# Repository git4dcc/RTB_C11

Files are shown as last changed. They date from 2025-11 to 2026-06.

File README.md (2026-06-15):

# RTB_C11





Smart Power Protection: This homebrew powerboard actively monitors input voltage to safeguard connected RTB modules. It automatically interrupts power to the RTB subsystem if the voltage drifts outside the **safe range of 12V to 18V**, preventing damage from erroneous power conditions.

<details>
<summary>See also</summary>

- [RTB_C10 - Master](/../../../../git4dcc/RTB_C10)
- [RTB_C12 - Micro Booster](/../../../../git4dcc/RTB_C12)
- [RTB_C13 - Track Sensor](/../../../../git4dcc/RTB_C13)
- [RTB_P15 - Base](/../../../../git4dcc/RTB_P15)

</details>

<details>
<summary>User Guides</summary>

- User Guide - DE
- [User Guide - EN](https://rtb4dcc.de/rtb_user_guide_en/)

</details>

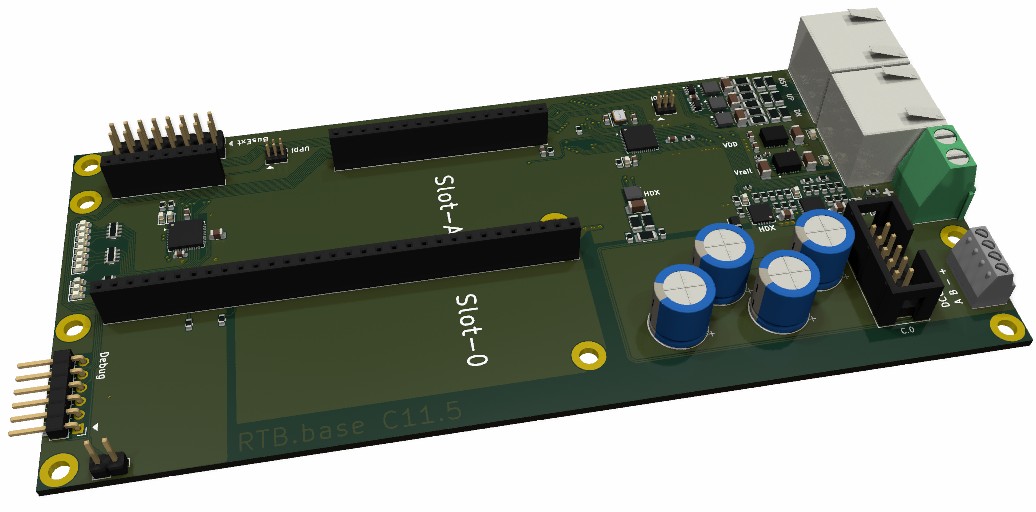
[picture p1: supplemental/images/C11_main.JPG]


## Powerboard features
- **FDX bus**
  - 2Mbps full duplex, RS-485 differential
- **HDX bus**
  - 2Mb, half duplex, RS-485 differential
  - up to 2A DCC continuous current
  - up to 2A HDX continuous current
- **Power input**
  - Under-, Over-, Reverse voltage protection
  - 14-18V DC, >4A
  - Soft start
  - Short circuit detection with software configurable latch-off, hiccup or current limiter mode
- **Expansion slots**
  - Bus Master Slot (Slot-A)
  - Booster Slot (Slot-0)
- firmware update over the bus

# Hardware
The PCB layout uses SMD footprints with 0.4mm pitch and a mix of 0603 and 0402 parts. Reflow soldering is mandatory.

| top | bottom |
| --- | --- |
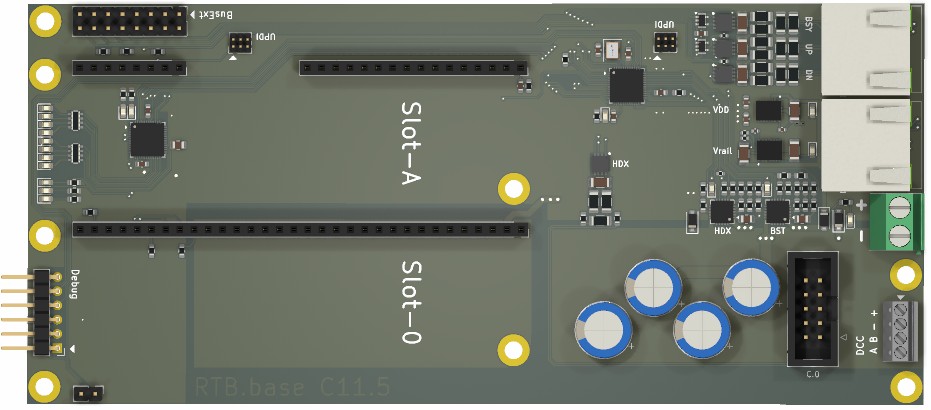
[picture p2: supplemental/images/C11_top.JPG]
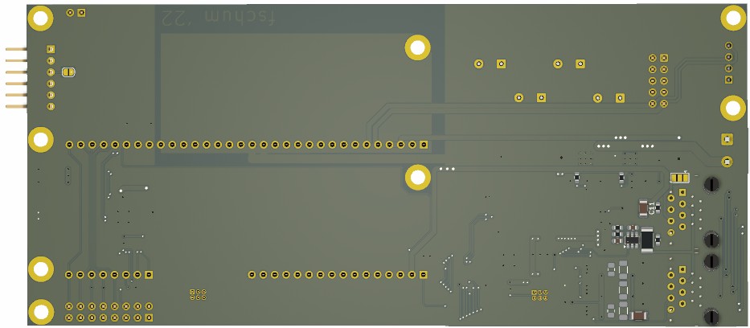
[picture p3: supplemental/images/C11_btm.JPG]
|  |  |

## PCB
- 2-layer PCB, FR4, 1.6mm
- CPU: AVR64DA48, Atmega4809
- PMIC: MAX17613AATP+

## Kicad
[Schematic](doc/C11_schematic.pdf) | [Layout](doc/C11_layout.pdf) | [Gerber](gerber)

# Firmware
Filename structure: { **pcb** }{ **code** }{ **version** }.hex

Example: **C11F0001**.hex

| | Description |
| --- | --- |
| **pcb** | Name of matching hardware (**C11**) |
| **code** | Type of code contained (**R**=rom, **B**=bootloader, **F**=flash, **U**=bld update, **P**=UPDI factory code) |
| **version** | Release version (**####**) |

[Firmware files](firmware)

## UPDI / Fuses
The fuse settings as well as the P-code (C11Pxxxx.hex) has to be installed by using UPDI.<br>

| Fuses Setting |
| --- |
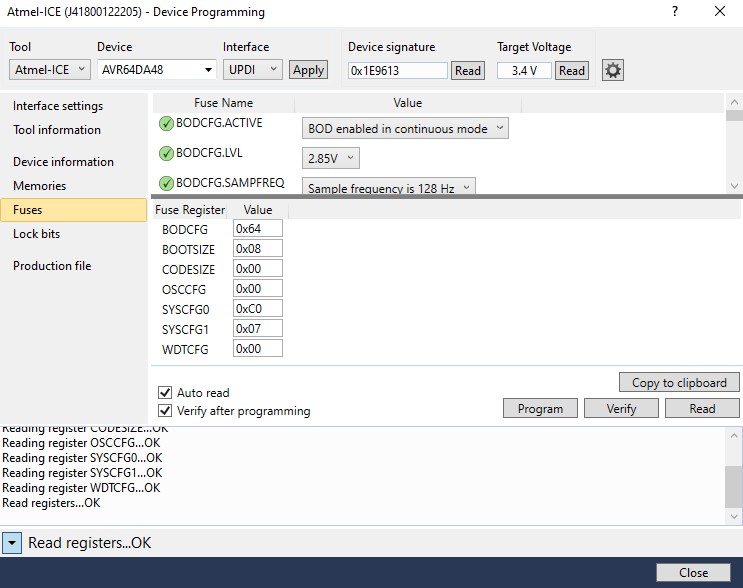
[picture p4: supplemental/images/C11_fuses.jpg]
||

# Images
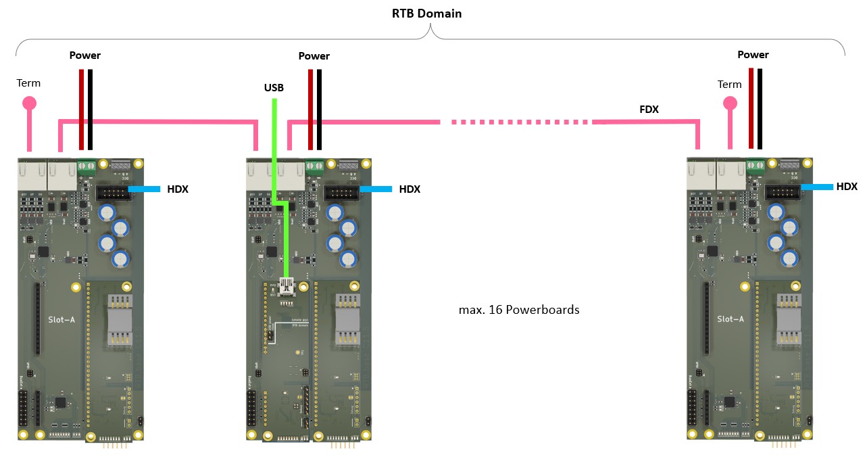
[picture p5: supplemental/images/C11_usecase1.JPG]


| Standalone | Closeup | FDX + HDX bus connected |
| --- | --- | --- |
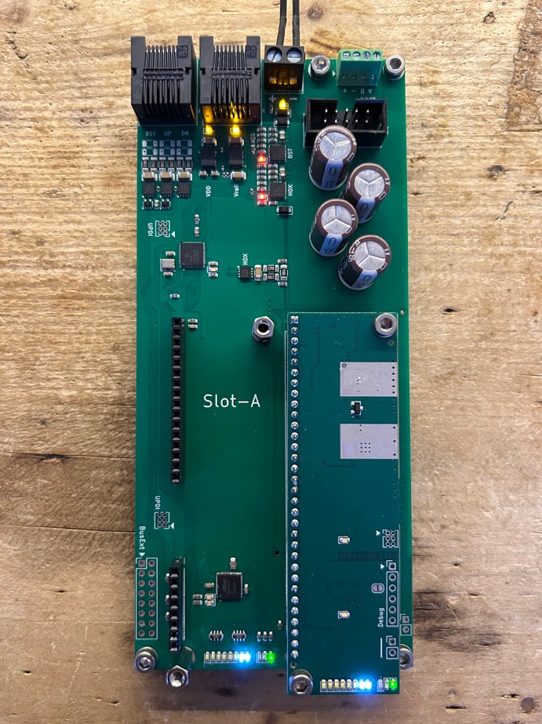
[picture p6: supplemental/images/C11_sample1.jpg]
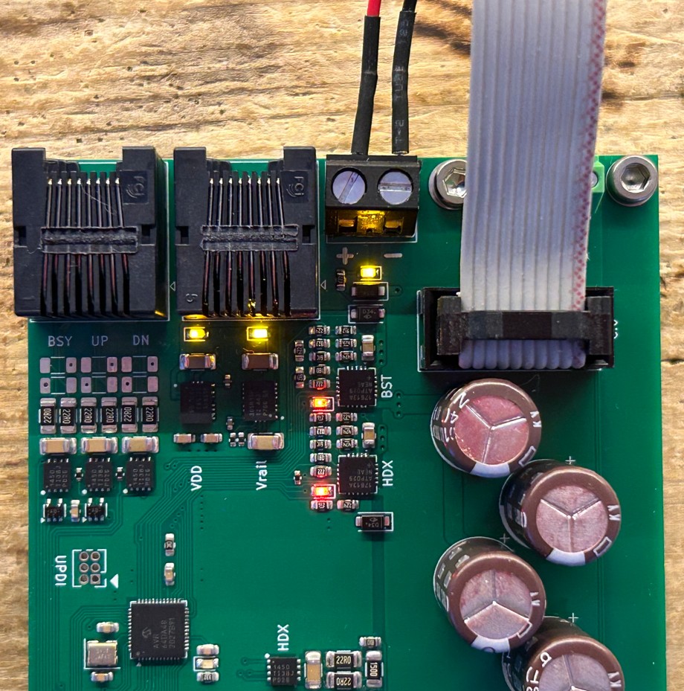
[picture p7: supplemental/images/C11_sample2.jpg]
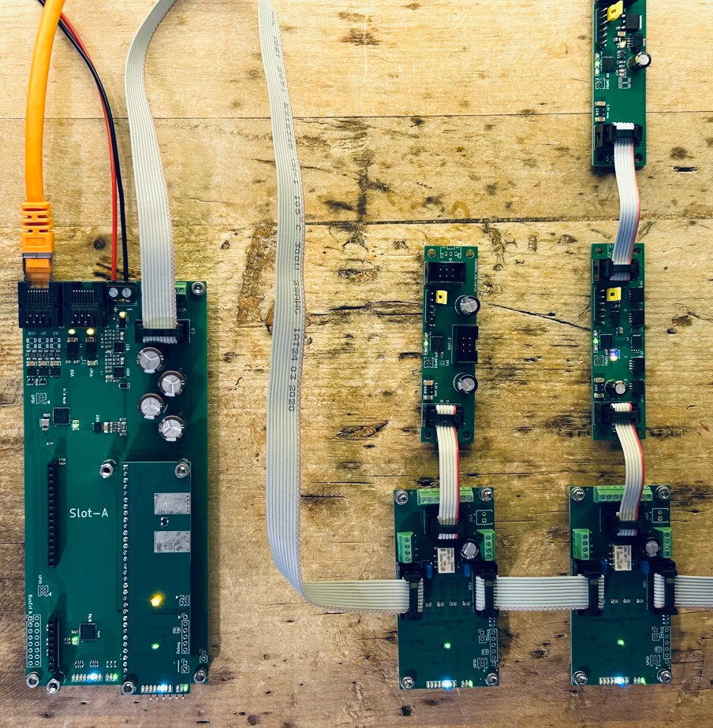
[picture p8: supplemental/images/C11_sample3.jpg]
|  |  |  |

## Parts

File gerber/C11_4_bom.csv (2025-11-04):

Designator | Footprint | Quantity | Value | LCSC Part #
C10, C2, C27, C7, C8, C9 | 1206 | 6 | 2.2u/50V | C50254
C11, C26 | 1206 | 2 | 10u | C694197
C12, C31 | 0603 | 2 | 10u/25V | C96446
C13, C21, C22, C24, C25, C28, C3, C5, C6 | 0603 | 9 | 100n | C14663
C14, C16 | 0805 | 2 | 1u/50V | C28323
C19 | 1206 | 1 | 2.2u | C50254
C20 | 0805 | 1 | 100n | C49678
C23 | 0603 | 1 | 2.2u | C50254
C32, C4 | 0402 | 2 | 1u | C52923
D1, D5, D9 | D_SOD-123F | 3 | SSA34 | C84632
IC1, IC7 | TPSM365R3RDNR | 2 | TPSM365R15RDNR | C22427405
IC2, IC3, IC4, IC5 | SON65P300X300X100-9N-D | 4 | THVD1450DRBR | C1850226
IC6, IC8 | UQFN-20-1EP_4x4mm_P0.5mm_EP2.8x2.8mm_ThermalVias | 2 | MAX17613AATP+ | C3198161
R1 | 0402 | 1 | 100k | C25741
R11 | 1206 | 1 | 150 | C17917
R12, R14, R18, R19 | 0603 | 4 | 220k | C22961
R13, R20, R27, R28 | 0603 | 4 | 9.1k | C23260
R2 | 0402 | 1 | 9.1k | C25926
R21, R23, R36, R38, R43, R45 | 0603 | 6 | 470k | C23178
R22, R37 | 0603 | 2 | 42.2k | C23167
R24, R39 | 0603 | 2 | 82k | C23254
R25, R40 | 0603 | 2 | 150k | C22807
R26, R41 | 0603 | 2 | 2.2k | C4190
R29, R46, R47, R49, R50, R72, R80, R81, R91 | 0603 | 9 | 3.3k | C22978
R4, R82, R88, R9, R90 | 0603 | 5 | 10k | C25804
R42 | 2010 | 1 | 0.05 | C912938
R51, R52, R53 | 0603 | 3 | 4.7k | C23162
R56, R57, R60, R61, R62, R63 | 1206 | 6 | 390 | C25378
R58, R59, R64, R65, R66, R67, R76, R77 | 1206 | 8 | 22 | C17958
R7, R8 | 0603 | 2 | 1k | C21190
R71 | 0603 | 1 | 33k | C4216
R83, R89 | 0603 | 2 | 22k | C31850
R84, R85 | 0402 | 2 | 100 | C25076
R87 | 0402 | 1 | 10k | C25744
RN1, RN2 | R_Array_Concave_4x0603 | 2 | 4.7k | C1980
U1 | QFN-48-1EP_6x6mm_P0.4mm_EP4.2x4.2mm | 1 | AVR64DA48 | C3227406
U3, U4 | SOT-353_SC-70-5 | 2 | 74AHC1G02 | C554271
U7 | SOT-23-6 | 1 | INA181A1 | C2058943
U9 | QFN-48-1EP_6x6mm_P0.4mm_EP4.2x4.2mm | 1 | ATmega4809-A
X1 | Oscillator_SMD_Abracon_ASE-4Pin_3.2x2.5mm | 1 | ASE-24MHz

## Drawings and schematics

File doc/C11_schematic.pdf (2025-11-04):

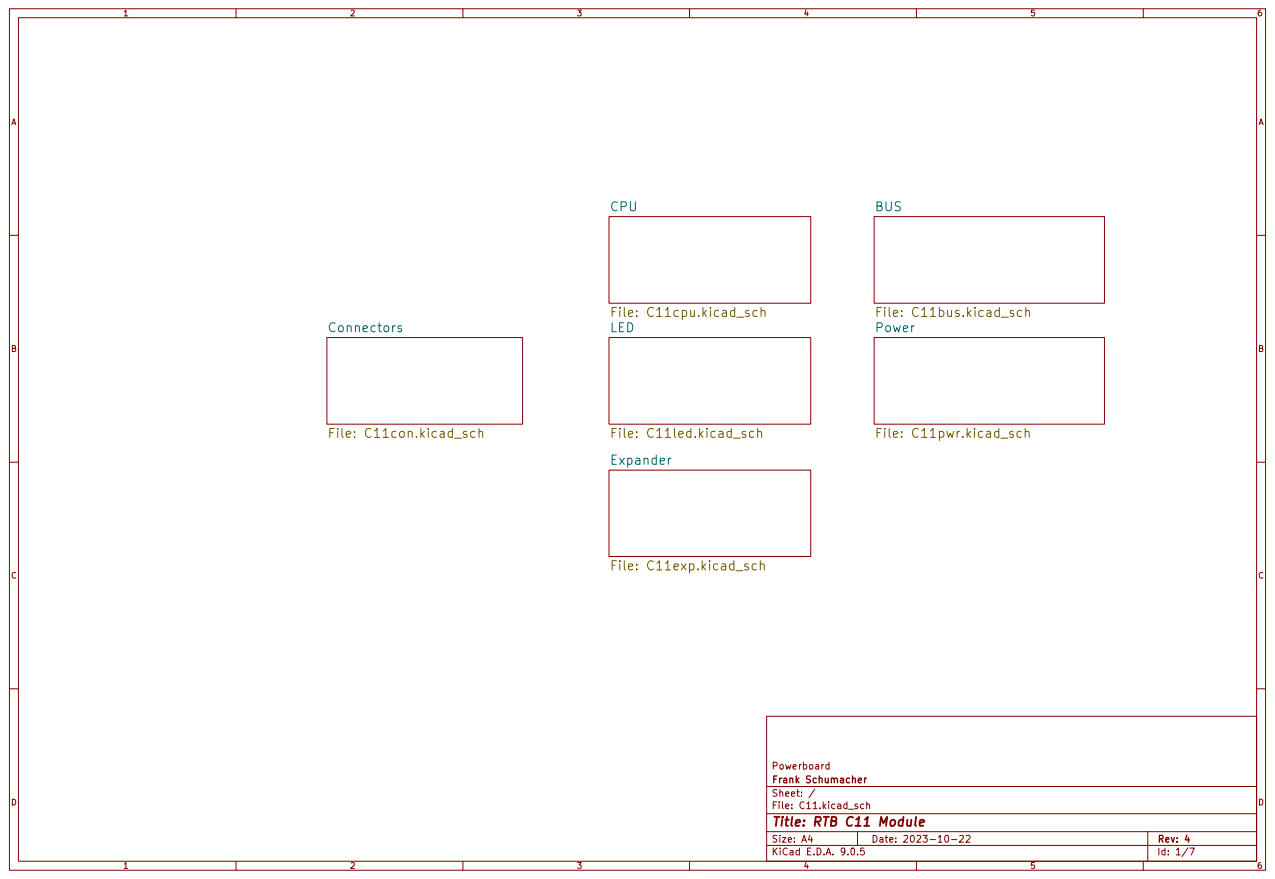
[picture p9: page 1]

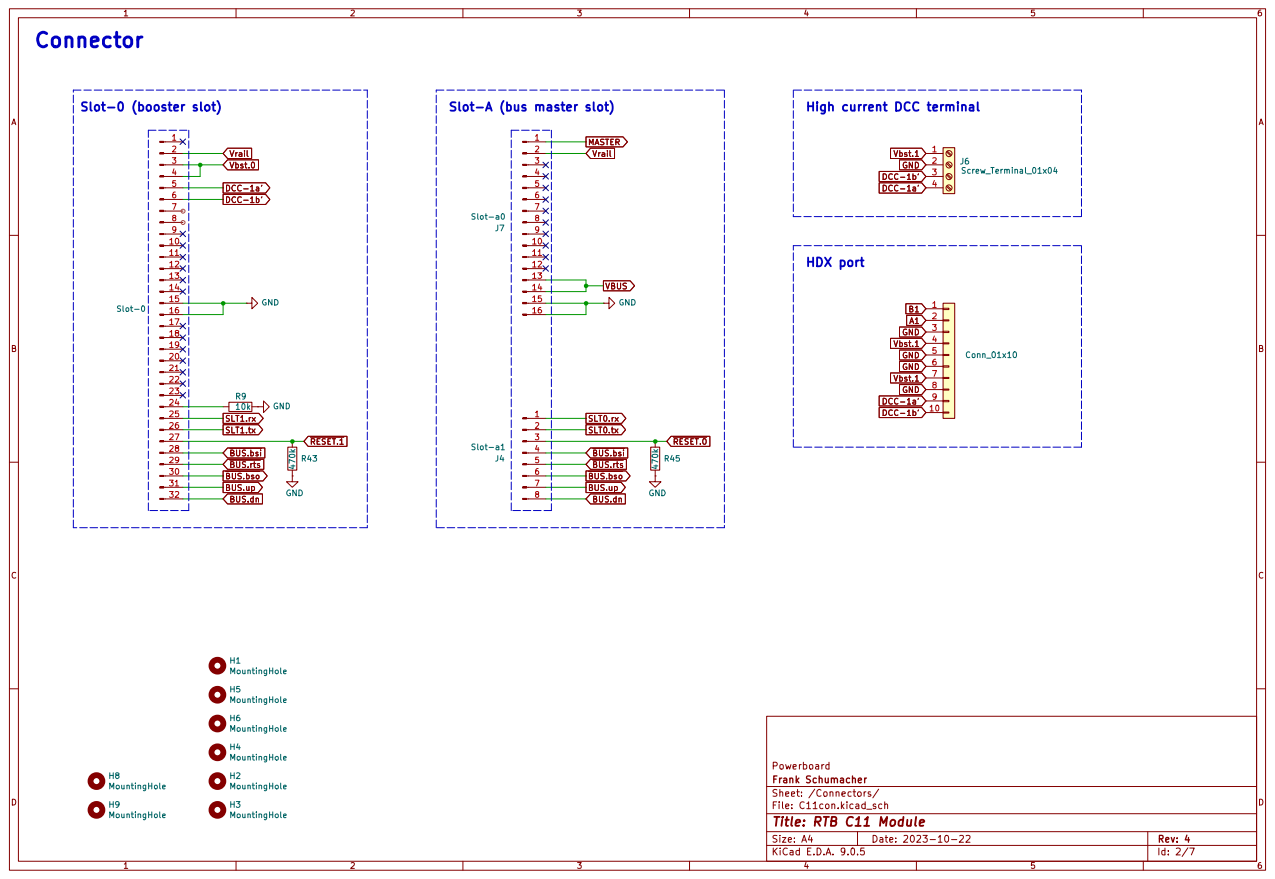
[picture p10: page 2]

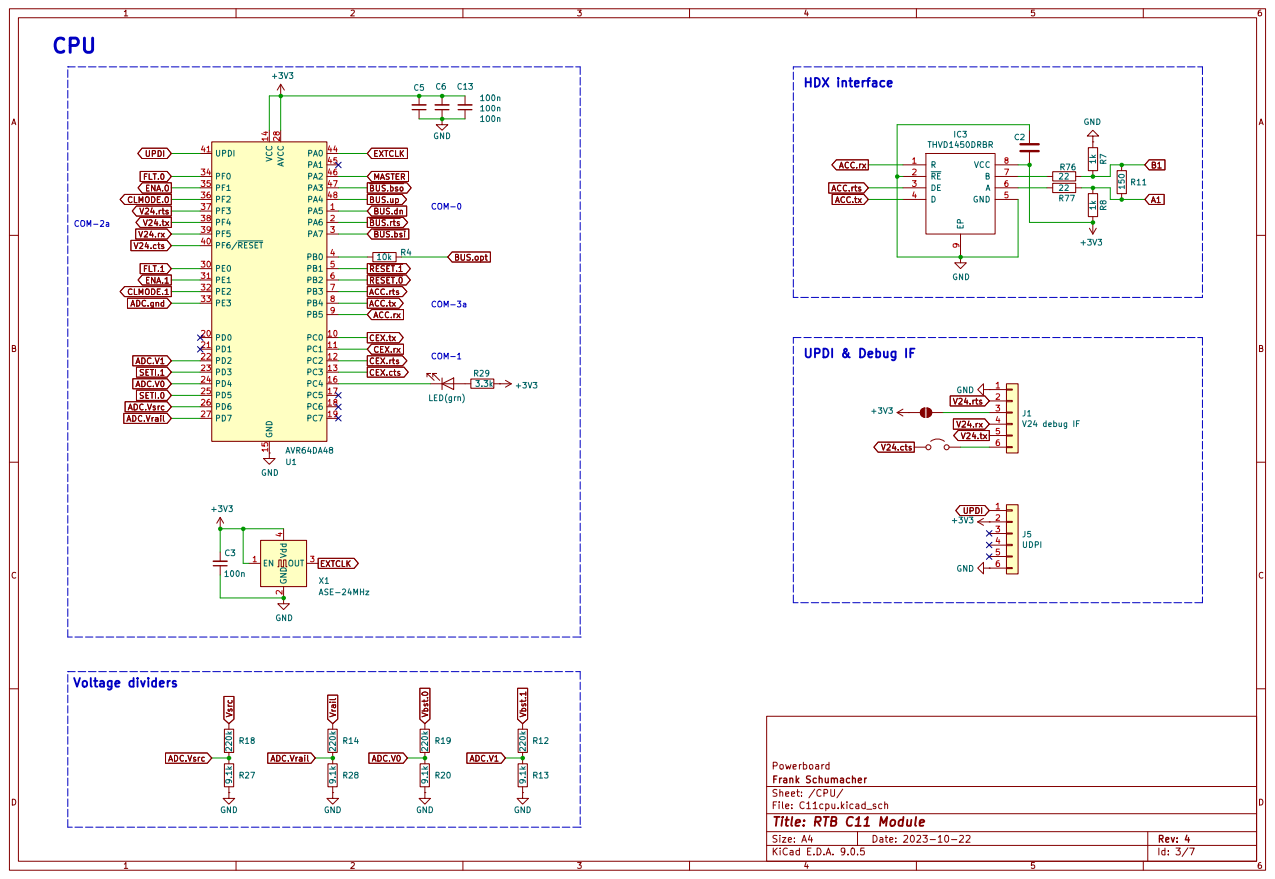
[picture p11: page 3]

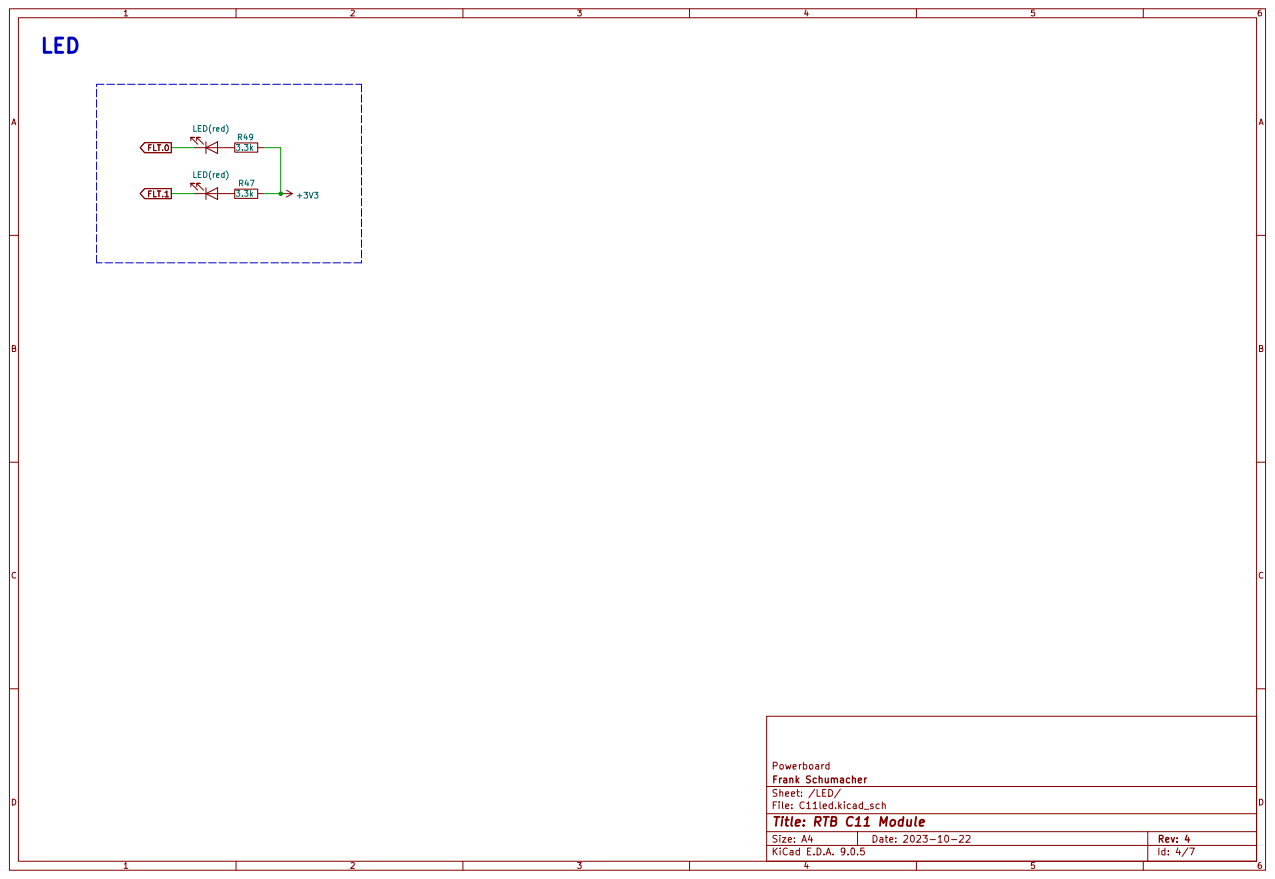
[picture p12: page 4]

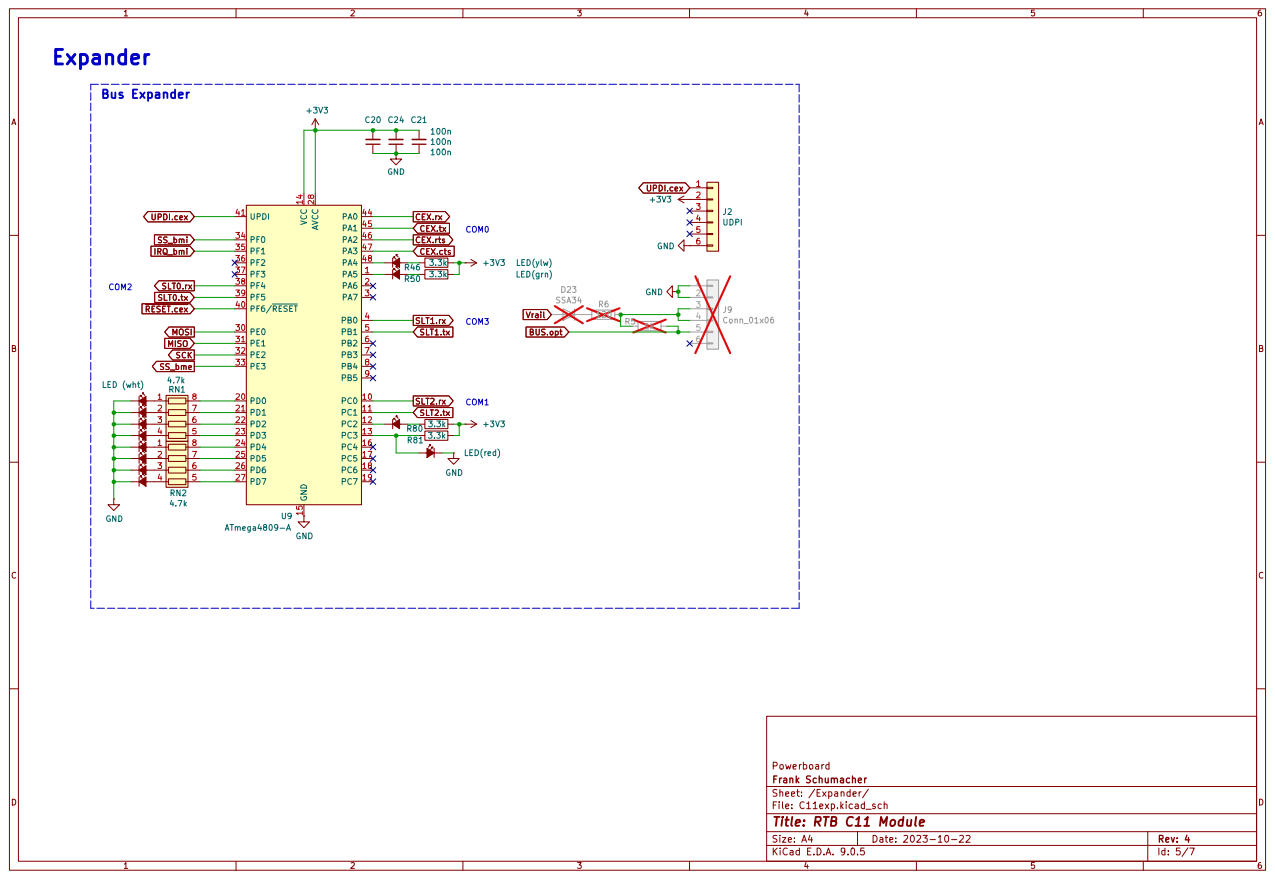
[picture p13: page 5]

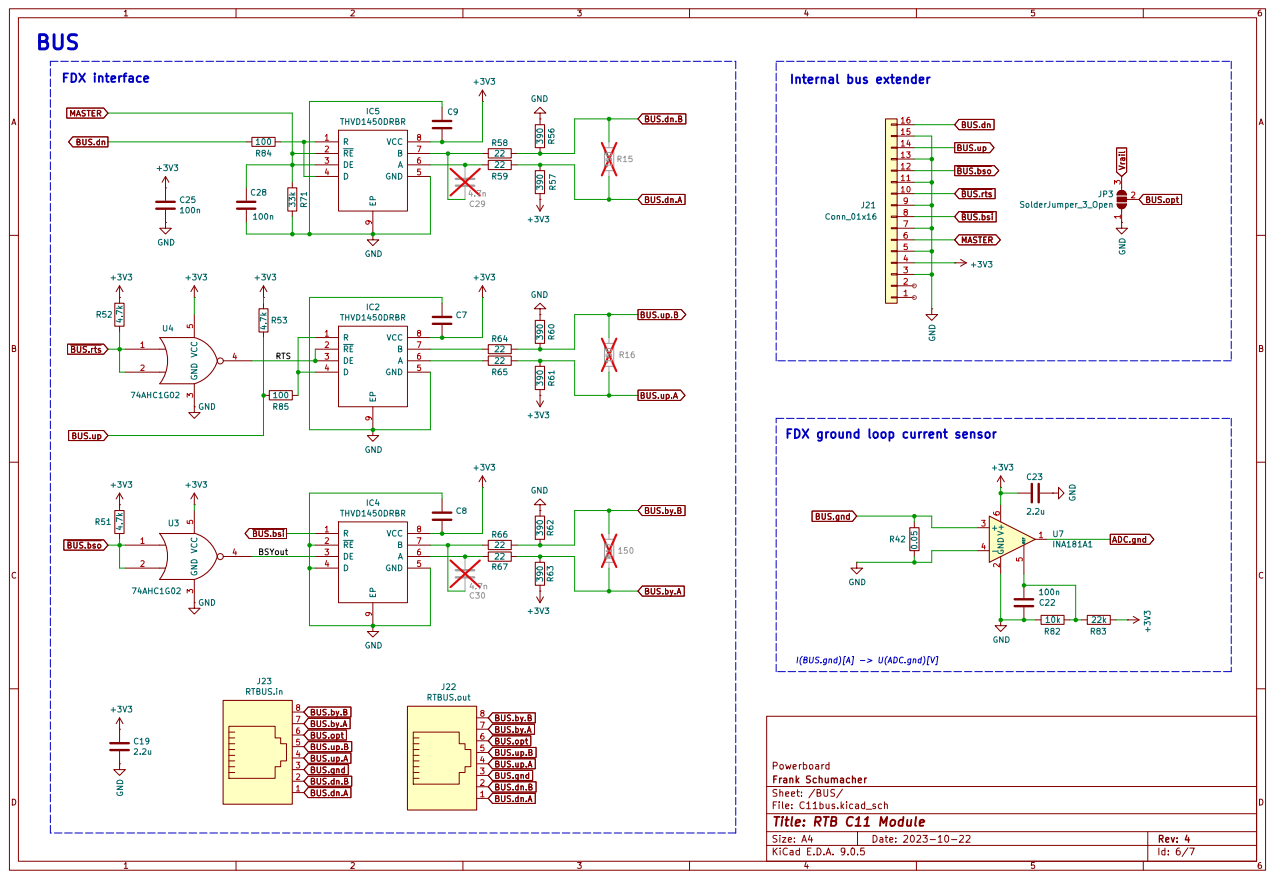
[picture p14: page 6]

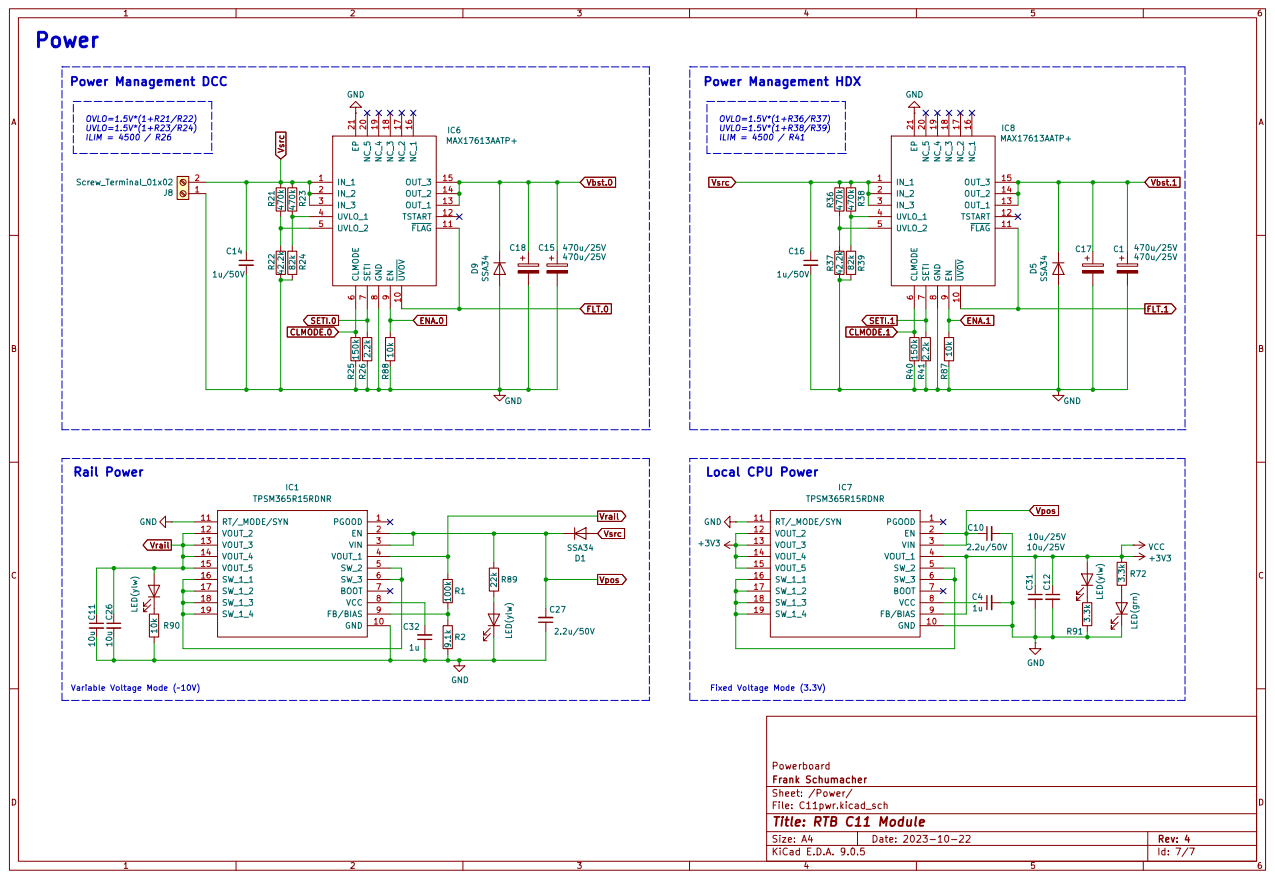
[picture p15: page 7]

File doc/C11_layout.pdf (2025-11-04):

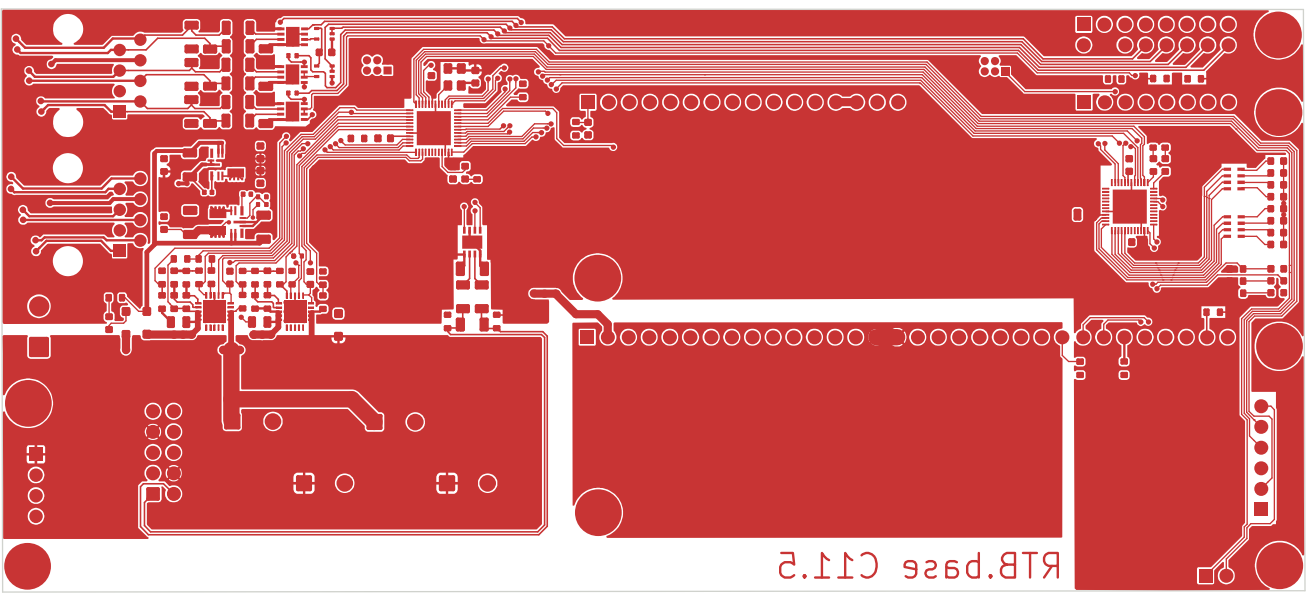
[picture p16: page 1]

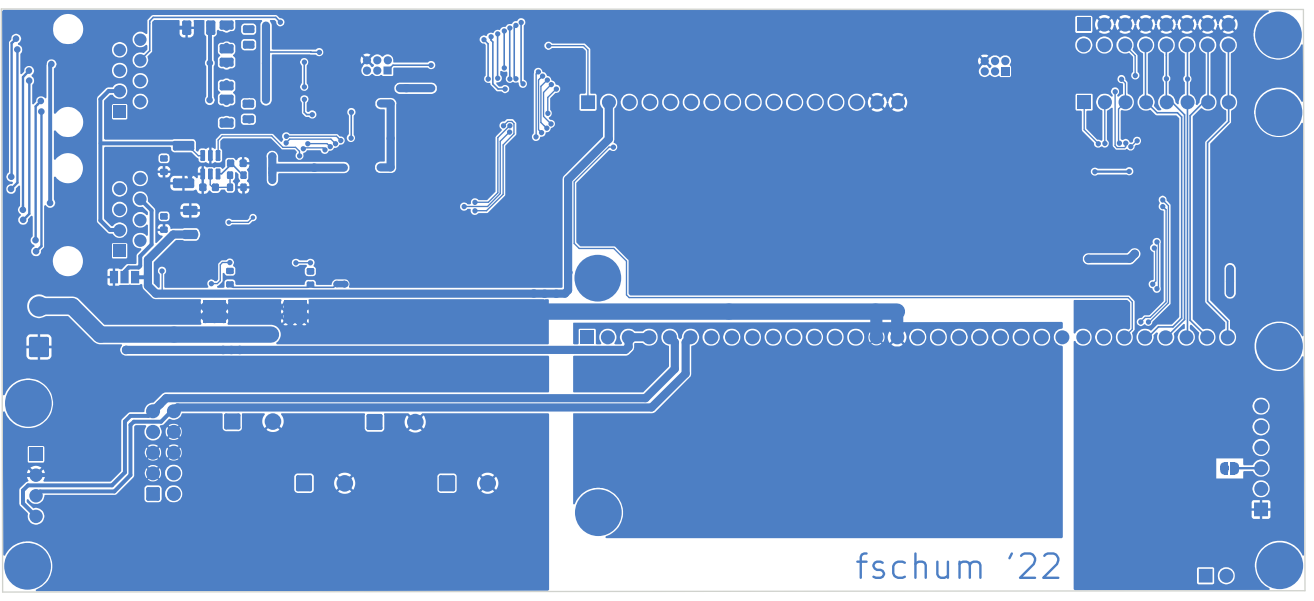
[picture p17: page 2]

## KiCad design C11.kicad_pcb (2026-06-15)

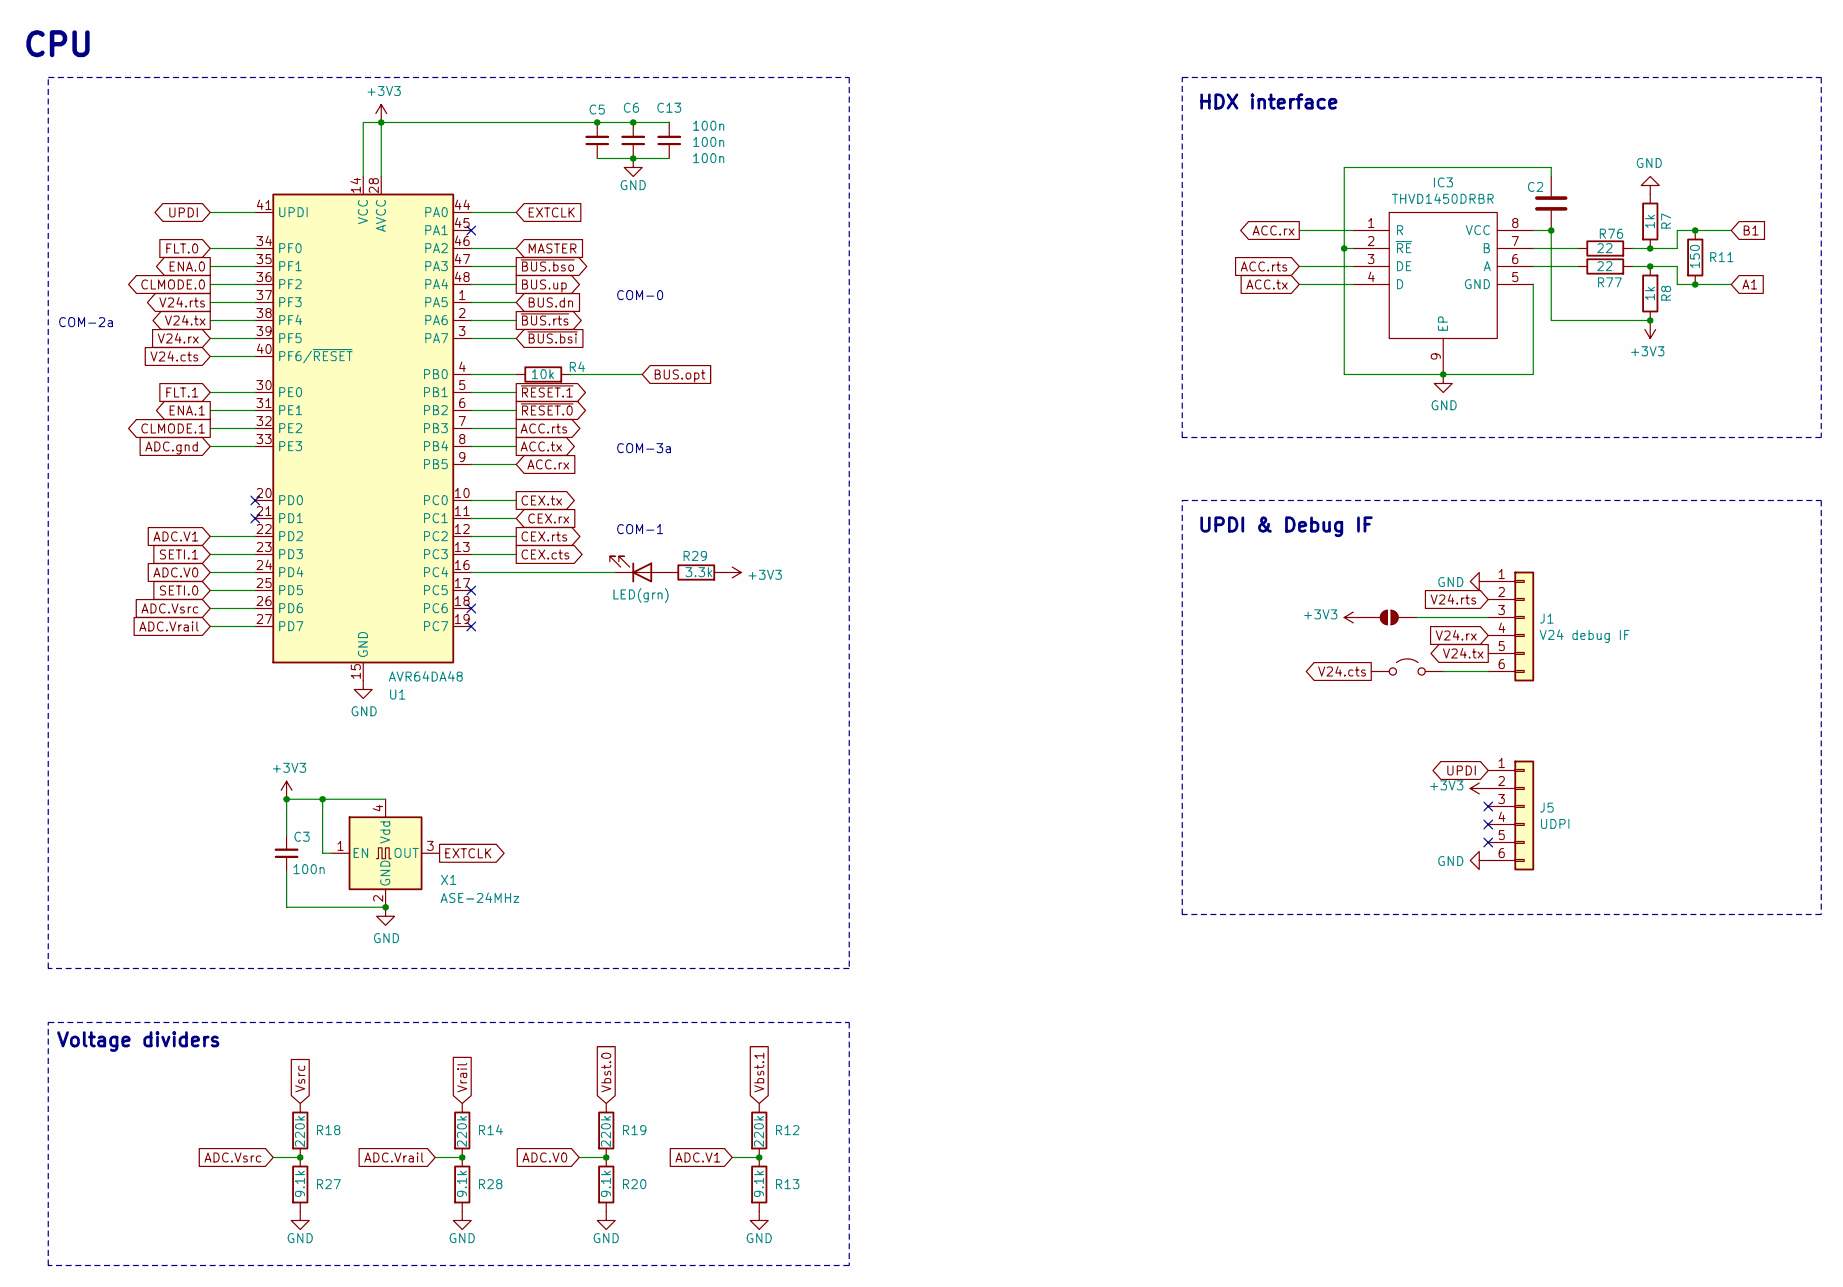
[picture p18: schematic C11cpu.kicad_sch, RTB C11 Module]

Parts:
C2: 2.2u/50V; C_1206_3216Metric; LCSC Part # C50254
C3, C5, C6, C13: 100n; C_0603_1608Metric; LCSC Part # C14663
D3: LED(grn); LED_0603_1608Metric
IC3: THVD1450DRBR; SON65P300X300X100-9N-D; LCSC Part # C1850226
J1: V24 debug IF; PinHeader_1x06_P2.54mm_Horizontal
J5: UDPI; PinHeader_2x03_P1.27mm_Vertical
JP1: SolderJumper_2_Open; SolderJumper-2_P1.3mm_Open_RoundedPad1.0x1.5mm
JP2: Jumper_2_Open; PinHeader_1x02_P2.54mm_Vertical
R4: 10k; R_0603_1608Metric; LCSC Part # C25804
R7, R8: 1k; R_0603_1608Metric; LCSC Part # C21190
R11: 150; R_1206_3216Metric; LCSC Part # C17917
R12, R14, R18, R19: 220k; R_0603_1608Metric; LCSC Part # C22961
R13, R20, R27, R28: 9.1k; R_0603_1608Metric; LCSC Part # C23260
R29: 3.3k; R_0603_1608Metric; LCSC Part # C22978
R76, R77: 22; R_1206_3216Metric; LCSC Part # C17958
U1: AVR64DA48; QFN-48-1EP_6x6mm_P0.4mm_EP4.2x4.2mm; LCSC Part # C3227406
X1: ASE-24MHz; Oscillator_SMD_Abracon_ASE-4Pin_3.2x2.5mm

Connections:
+3V3: C2.2, C3.2, C5.2, C6.2, C13.2, IC3.8 (VCC), J5.2, JP1.2 (B), R8.1, R29.2, U1.14 (VCC), U1.28 (AVCC), U1.42 (VCC), X1.1 (EN), X1.4 (Vdd); also elsewhere on the board
A1: R8.2, R11.2, R77.2; also elsewhere on the board
ACC.rts: IC3.3 (DE), U1.7 (PB3)
ACC.rx: IC3.1 (R), U1.9 (PB5)
ACC.tx: IC3.4 (D), U1.8 (PB4)
ADC.V0: R19.2, R20.1, U1.24 (PD4)
ADC.V1: R12.2, R13.1, U1.22 (PD2)
ADC.Vrail: R14.2, R28.1, U1.27 (PD7)
ADC.Vsrc: R18.2, R27.1, U1.26 (PD6)
ADC.gnd: U1.33 (PE3); also elsewhere on the board
B1: R7.2, R11.1, R76.2; also elsewhere on the board
BUS.dn: U1.1 (PA5); also elsewhere on the board
BUS.opt: R4.2; also elsewhere on the board
BUS.up: U1.48 (PA4); also elsewhere on the board
CEX.cts: U1.13 (PC3); also elsewhere on the board
CEX.rts: U1.12 (PC2); also elsewhere on the board
CEX.rx: U1.11 (PC1); also elsewhere on the board
CEX.tx: U1.10 (PC0); also elsewhere on the board
CLMODE.0: U1.36 (PF2); also elsewhere on the board
CLMODE.1: U1.32 (PE2); also elsewhere on the board
ENA.0: U1.35 (PF1); also elsewhere on the board
ENA.1: U1.31 (PE1); also elsewhere on the board
EXTCLK: U1.44 (PA0), X1.3 (OUT)
FLT.0: U1.34 (PF0); also elsewhere on the board
FLT.1: U1.30 (PE0); also elsewhere on the board
GND: C2.1, C3.1, C5.1, C6.1, C13.1, IC3.2 (~RE), IC3.5 (GND), IC3.9 (EP), J1.1, J5.6, R7.1, R13.2, R20.2, R27.2, R28.2, U1.15 (GND), U1.29 (GND), U1.43 (GND), U1.49, X1.2 (GND); also elsewhere on the board
MASTER: U1.46 (PA2); also elsewhere on the board
unnamed: D3.2 (A), R29.1
unnamed: D3.1 (K), U1.16 (PC4)
unnamed: IC3.6 (A), R77.1
unnamed: IC3.7 (B), R76.1
unnamed: J1.3, JP1.1 (A)
unnamed: J1.6, JP2.2 (B)
unnamed: R4.1, U1.4 (PB0)
SETI.0: U1.25 (PD5); also elsewhere on the board
SETI.1: U1.23 (PD3); also elsewhere on the board
UPDI: J5.1, U1.41 (UPDI)
V24.cts: JP2.1 (A), U1.40 (PF6/~RESET)
V24.rts: J1.2, U1.37 (PF3)
V24.rx: J1.4, U1.39 (PF5)
V24.tx: J1.5, U1.38 (PF4)
Vbst.0: R19.1; also elsewhere on the board
Vbst.1: R12.1; also elsewhere on the board
Vrail: R14.1; also elsewhere on the board
Vsrc: R18.1; also elsewhere on the board
~BUS.bsi: U1.3 (PA7); also elsewhere on the board
~BUS.bso: U1.47 (PA3); also elsewhere on the board
~BUS.rts: U1.2 (PA6); also elsewhere on the board
~RESET.0: U1.6 (PB2); also elsewhere on the board
~RESET.1: U1.5 (PB1); also elsewhere on the board

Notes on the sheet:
UPDI & Debug IF
Voltage dividers
COM-2a
COM-1
HDX interface
CPU
COM-0
COM-3a

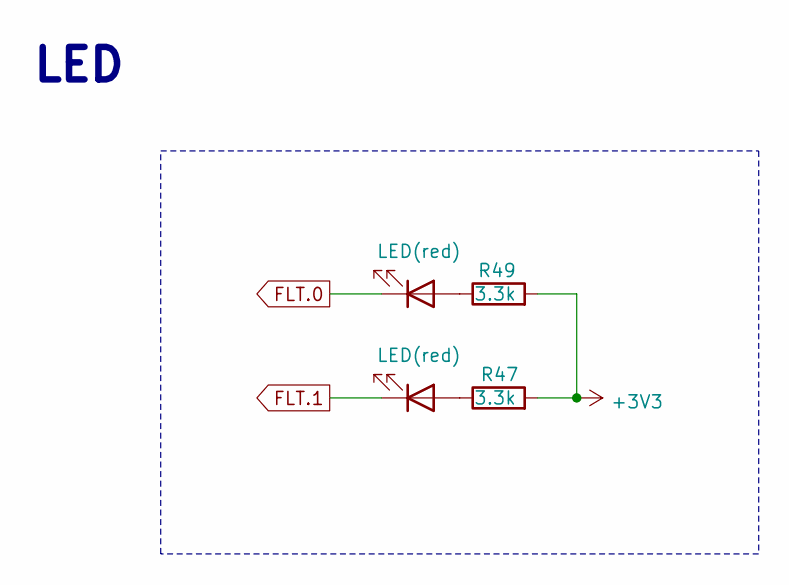
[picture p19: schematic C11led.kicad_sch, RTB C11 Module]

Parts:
D6, D8: LED(red); LED_0603_1608Metric
R47, R49: 3.3k; R_0603_1608Metric; LCSC Part # C22978

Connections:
+3V3: R47.2, R49.2; also elsewhere on the board
FLT.0: D8.1 (K); also elsewhere on the board
FLT.1: D6.1 (K); also elsewhere on the board
unnamed: D6.2 (A), R47.1
unnamed: D8.2 (A), R49.1

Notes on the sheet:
LED

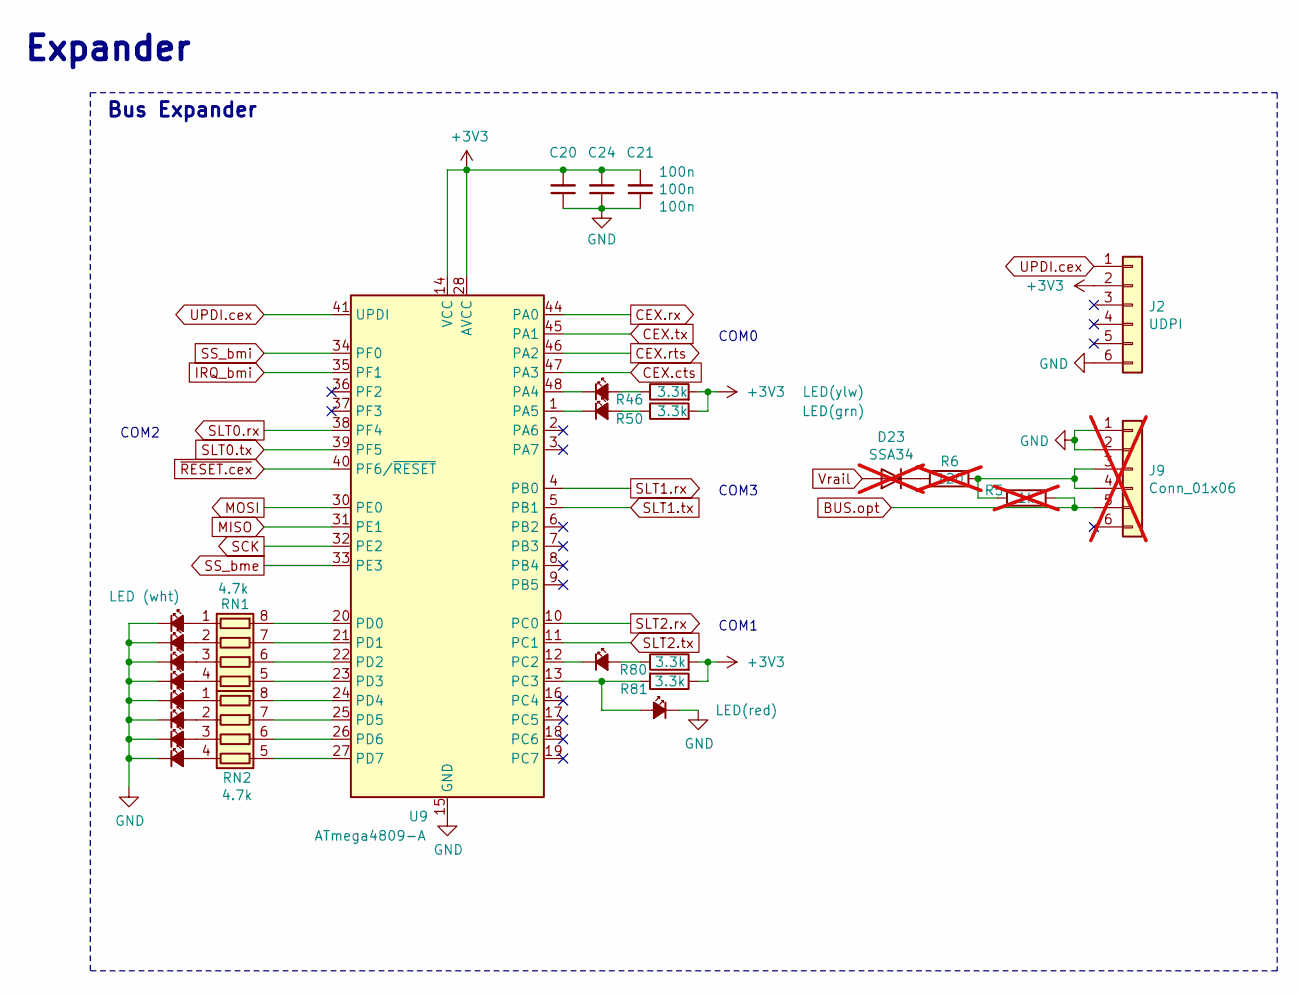
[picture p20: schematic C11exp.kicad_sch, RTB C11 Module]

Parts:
C20: 100n; C_0805_2012Metric; LCSC Part # C49678
C21, C24: 100n; C_0603_1608Metric; LCSC Part # C14663
D10: LED(ylw); LED_0603_1608Metric
D11: LED(grn); LED_0603_1608Metric
D12: LED(blu); LED_0603_1608Metric
D13: LED(red); LED_0603_1608Metric
D15: LED (wht); LED_0603_1608Metric
D16, D17, D18, D19, D20, D21, D22: LED_Small_ALT; LED_0603_1608Metric
D23: SSA34; D_SOD-123F; LCSC Part # C84632; not fitted
J2: UDPI; PinHeader_2x03_P1.27mm_Vertical
J9: Conn_01x06; PinHeader_1x06_P2.54mm_Vertical; not fitted
R5: 1k; R_1206_3216Metric; LCSC Part # C4410; not fitted
R6: 120; R_1206_3216Metric; LCSC Part # C17909; not fitted
R46, R50, R80, R81: 3.3k; R_0603_1608Metric; LCSC Part # C22978
RN1, RN2: 4.7k; R_Array_Concave_4x0603; LCSC Part # C1980
U9: ATmega4809-A; QFN-48-1EP_6x6mm_P0.4mm_EP4.2x4.2mm

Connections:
+3V3: C20.2, C21.2, C24.2, J2.2, R46.2, R50.2, R80.2, R81.1, U9.14 (VCC), U9.28 (AVCC), U9.42 (VCC); also elsewhere on the board
CEX.cts: U9.47 (PA3); also elsewhere on the board
CEX.rts: U9.46 (PA2); also elsewhere on the board
CEX.rx: U9.44 (PA0); also elsewhere on the board
CEX.tx: U9.45 (PA1); also elsewhere on the board
GND: C20.1, C21.1, C24.1, D13.1 (K), D15.1 (K), D16.1 (K), D17.1 (K), D18.1 (K), D19.1 (K), D20.1 (K), D21.1 (K), D22.1 (K), J2.6, J9.1, J9.2, U9.15 (GND), U9.29 (GND), U9.43 (GND), U9.49; also elsewhere on the board
IRQ_bmi: U9.35 (PF1)
MISO: U9.31 (PE1)
MOSI: U9.30 (PE0)
unnamed: D10.2 (A), R46.1
unnamed: D10.1 (K), U9.48 (PA4)
unnamed: D11.2 (A), R50.1
unnamed: D11.1 (K), U9.1 (PA5)
unnamed: D12.2 (A), R80.1
unnamed: D12.1 (K), U9.12 (PC2)
unnamed: D13.2 (A), R81.2, U9.13 (PC3)
unnamed: D15.2 (A), RN1.1 (R1.1)
unnamed: D16.2 (A), RN1.2 (R2.1)
unnamed: D17.2 (A), RN1.3 (R3.1)
unnamed: D18.2 (A), RN1.4 (R4.1)
unnamed: D19.2 (A), RN2.1 (R1.1)
unnamed: D20.2 (A), RN2.2 (R2.1)
unnamed: D21.2 (A), RN2.3 (R3.1)
unnamed: D22.2 (A), RN2.4 (R4.1)
unnamed: D23.1 (K), R6.2
unnamed: J9.3, J9.4, R5.2, R6.1
unnamed: J9.5, R5.1
unnamed: RN1.8 (R1.2), U9.20 (PD0)
unnamed: RN1.7 (R2.2), U9.21 (PD1)
unnamed: RN1.6 (R3.2), U9.22 (PD2)
unnamed: RN1.5 (R4.2), U9.23 (PD3)
unnamed: RN2.8 (R1.2), U9.24 (PD4)
unnamed: RN2.7 (R2.2), U9.25 (PD5)
unnamed: RN2.6 (R3.2), U9.26 (PD6)
unnamed: RN2.5 (R4.2), U9.27 (PD7)
SCK: U9.32 (PE2)
SLT0.rx: U9.38 (PF4); also elsewhere on the board
SLT0.tx: U9.39 (PF5); also elsewhere on the board
SLT1.rx: U9.4 (PB0); also elsewhere on the board
SLT1.tx: U9.5 (PB1); also elsewhere on the board
SLT2.rx: U9.10 (PC0)
SLT2.tx: U9.11 (PC1)
SS_bme: U9.33 (PE3)
SS_bmi: U9.34 (PF0)
UPDI.cex: J2.1, U9.41 (UPDI)
~RESET.cex: U9.40 (PF6/~RESET)

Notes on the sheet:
COM1
Expander
COM0
Bus Expander
COM2
COM3

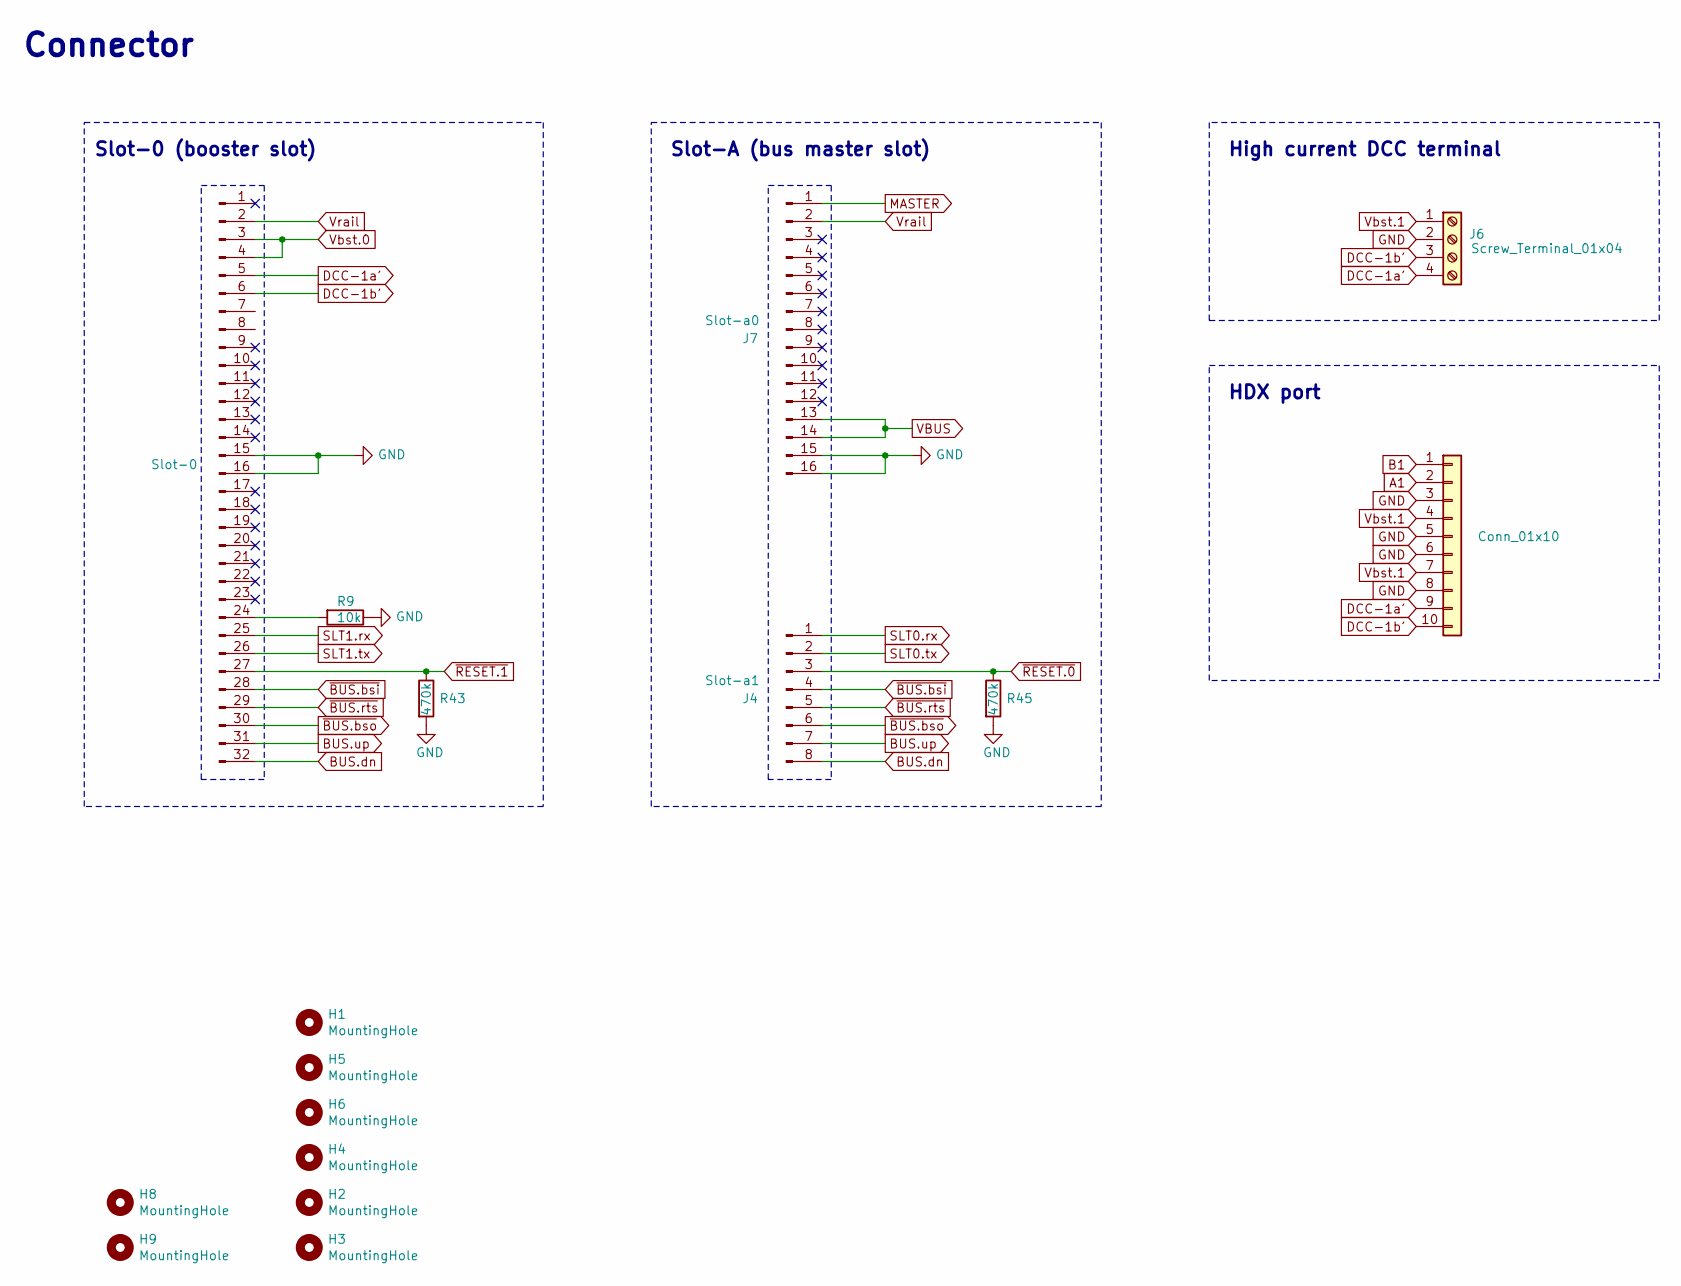
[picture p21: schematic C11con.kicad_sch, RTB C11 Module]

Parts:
C.0: Conn_01x10; IDC-Header_2x05_P2.54mm_Vertical
H1, H2, H3, H4, H5, H6, H8, H9: MountingHole; MountingHole_3.2mm_M3_ISO7380_Pad
J3: Slot-0; PinSocket_1x32_P2.54mm_Vertical
J4: Slot-a1; PinSocket_1x08_P2.54mm_Vertical
J6: Screw_Terminal_01x04; 1725672
J7: Slot-a0; PinSocket_1x16_P2.54mm_Vertical
R9: 10k; R_0603_1608Metric; LCSC Part # C25804
R43, R45: 470k; R_0603_1608Metric; LCSC Part # C23178

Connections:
A1: C.0.2; also elsewhere on the board
B1: C.0.1; also elsewhere on the board
BUS.dn: J3.32, J4.8; also elsewhere on the board
BUS.up: J3.31, J4.7; also elsewhere on the board
DCC-1a': C.0.9, J3.5, J6.4
DCC-1b': C.0.10, J3.6, J6.3
GND: C.0.3, C.0.5, C.0.6, C.0.8, J3.15, J3.16, J6.2, J7.15, J7.16, R9.1, R43.2, R45.2; also elsewhere on the board
MASTER: J7.1; also elsewhere on the board
unnamed: J3.24, R9.2
SLT0.rx: J4.1; also elsewhere on the board
SLT0.tx: J4.2; also elsewhere on the board
SLT1.rx: J3.25; also elsewhere on the board
SLT1.tx: J3.26; also elsewhere on the board
VBUS: J7.13, J7.14
Vbst.0: J3.3, J3.4; also elsewhere on the board
Vbst.1: C.0.4, C.0.7, J6.1; also elsewhere on the board
Vrail: J3.2, J7.2; also elsewhere on the board
~BUS.bsi: J3.28, J4.4; also elsewhere on the board
~BUS.bso: J3.30, J4.6; also elsewhere on the board
~BUS.rts: J3.29, J4.5; also elsewhere on the board
~RESET.0: J4.3, R45.1; also elsewhere on the board
~RESET.1: J3.27, R43.1; also elsewhere on the board

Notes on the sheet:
Slot-A (bus master slot)
HDX port
High current DCC terminal
Connector
Slot-0 (booster slot)

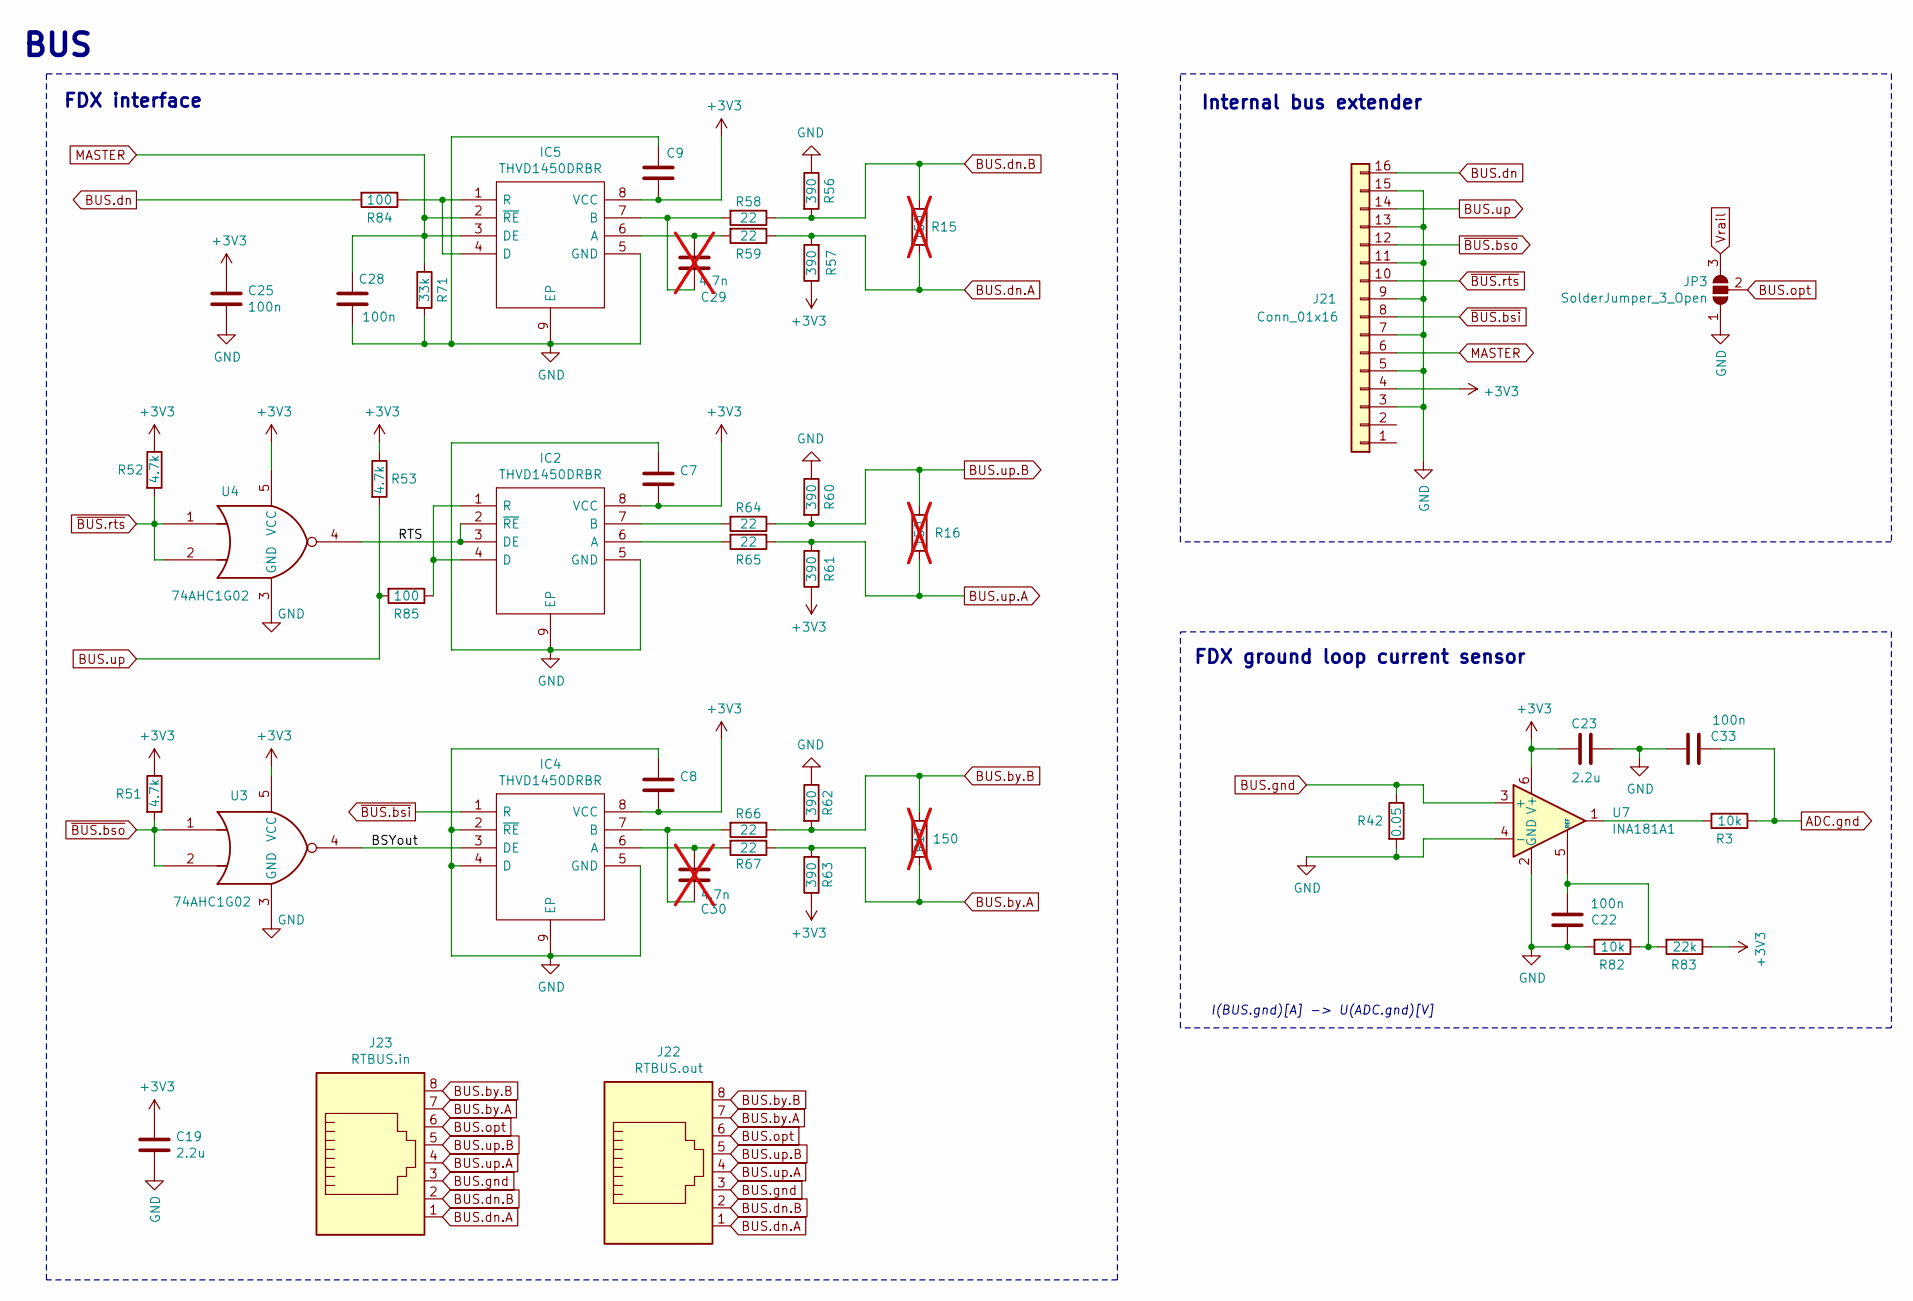
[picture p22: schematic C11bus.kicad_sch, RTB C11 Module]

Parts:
C7, C8, C9: 2.2u/50V; C_1206_3216Metric; LCSC Part # C50254
C19: 2.2u; C_1206_3216Metric; LCSC Part # C50254
C22, C25, C28, C33: 100n; C_0603_1608Metric; LCSC Part # C14663
C23: 2.2u; C_0603_1608Metric; LCSC Part # C50254
C29, C30: 4.7n; C_0805_2012Metric; not fitted
IC2, IC4, IC5: THVD1450DRBR; SON65P300X300X100-9N-D; LCSC Part # C1850226
J21: Conn_01x16; PinHeader_2x08_P2.54mm_Vertical
J22: RTBUS.out; RJ45_Amphenol_54602-x08_Horizontal
J23: RTBUS.in; RJ45_Amphenol_54602-x08_Horizontal
JP3: SolderJumper_3_Open; SolderJumper-3_P1.3mm_Open_Pad1.0x1.5mm
R3, R82: 10k; R_0603_1608Metric; LCSC Part # C25804
R15, R16, R17: 150; R_1206_3216Metric; not fitted
R42: 0.05; R_2010_5025Metric; LCSC Part # C912938
R51, R52, R53: 4.7k; R_0603_1608Metric; LCSC Part # C23162
R56, R57, R60, R61, R62, R63: 390; R_1206_3216Metric; LCSC Part # C25378
R58, R59, R64, R65, R66, R67: 22; R_1206_3216Metric; LCSC Part # C17958
R71: 33k; R_0603_1608Metric; LCSC Part # C4216
R83: 22k; R_0603_1608Metric; LCSC Part # C31850
R84, R85: 100; R_0402_1005Metric; LCSC Part # C25076
U3, U4: 74AHC1G02; SOT65P210X110-5N; LCSC Part # C554271
U7: INA181A1; SOT-23-6; LCSC Part # C2058943

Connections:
+3V3: C7.2, C8.2, C9.2, C19.1, C23.1, C25.1, IC2.8 (VCC), IC4.8 (VCC), IC5.8 (VCC), J21.4, R51.1, R52.1, R53.1, R57.1, R61.1, R63.1, R83.1, U3.5 (VCC), U4.5 (VCC), U7.6 (V+); also elsewhere on the board
/BUS/BSYout: IC4.3 (DE), U3.4
/BUS/RTS: IC2.2 (~RE), IC2.3 (DE), U4.4
ADC.gnd: C33.1, R3.1; also elsewhere on the board
BUS.by.A: J22.7, J23.7, R17.2, R63.2, R67.1
BUS.by.B: J22.8, J23.8, R17.1, R62.2, R66.1
BUS.dn: J21.16, R84.2; also elsewhere on the board
BUS.dn.A: J22.1, J23.1, R15.2, R57.2, R59.1
BUS.dn.B: J22.2, J23.2, R15.1, R56.2, R58.1
BUS.gnd: J22.3, J23.3, R42.1, U7.3 (+)
BUS.opt: J22.6, J23.6, JP3.2 (C); also elsewhere on the board
BUS.up: J21.14, R53.2, R85.2; also elsewhere on the board
BUS.up.A: J22.4, J23.4, R16.2, R61.2, R65.1
BUS.up.B: J22.5, J23.5, R16.1, R60.2, R64.1
GND: C7.1, C8.1, C9.1, C19.2, C22.1, C23.2, C25.2, C28.2, C33.2, IC2.5 (GND), IC2.9 (EP), IC4.2 (~RE), IC4.4 (D), IC4.5 (GND), IC4.9 (EP), IC5.5 (GND), IC5.9 (EP), J21.3, J21.5, J21.7, J21.9, J21.11, J21.13, J21.15, JP3.1 (A), R42.2, R56.1, R60.1, R62.1, R71.2, R82.2, U3.3 (GND), U4.3 (GND), U7.2 (GND), U7.4 (-); also elsewhere on the board
MASTER: C28.1, IC5.2 (~RE), IC5.3 (DE), J21.6, R71.1; also elsewhere on the board
unnamed: IC2.6 (A), R65.2
unnamed: IC2.7 (B), R64.2
unnamed: IC2.1 (R), IC2.4 (D), R85.1
unnamed: C30.1, IC4.6 (A), R67.2
unnamed: C30.2, IC4.7 (B), R66.2
unnamed: C29.1, IC5.6 (A), R59.2
unnamed: C29.2, IC5.7 (B), R58.2
unnamed: IC5.1 (R), IC5.4 (D), R84.1
unnamed: R3.2, U7.1
unnamed: C22.2, R82.1, R83.2, U7.5 (REF)
Vrail: JP3.3 (B); also elsewhere on the board
~BUS.bsi: IC4.1 (R), J21.8; also elsewhere on the board
~BUS.bso: J21.12, R51.2, U3.1, U3.2; also elsewhere on the board
~BUS.rts: J21.10, R52.2, U4.1, U4.2; also elsewhere on the board

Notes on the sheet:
FDX ground loop current sensor
BUS
FDX interface
Internal bus extender
I(BUS.gnd)[A] -> U(ADC.gnd)[V]

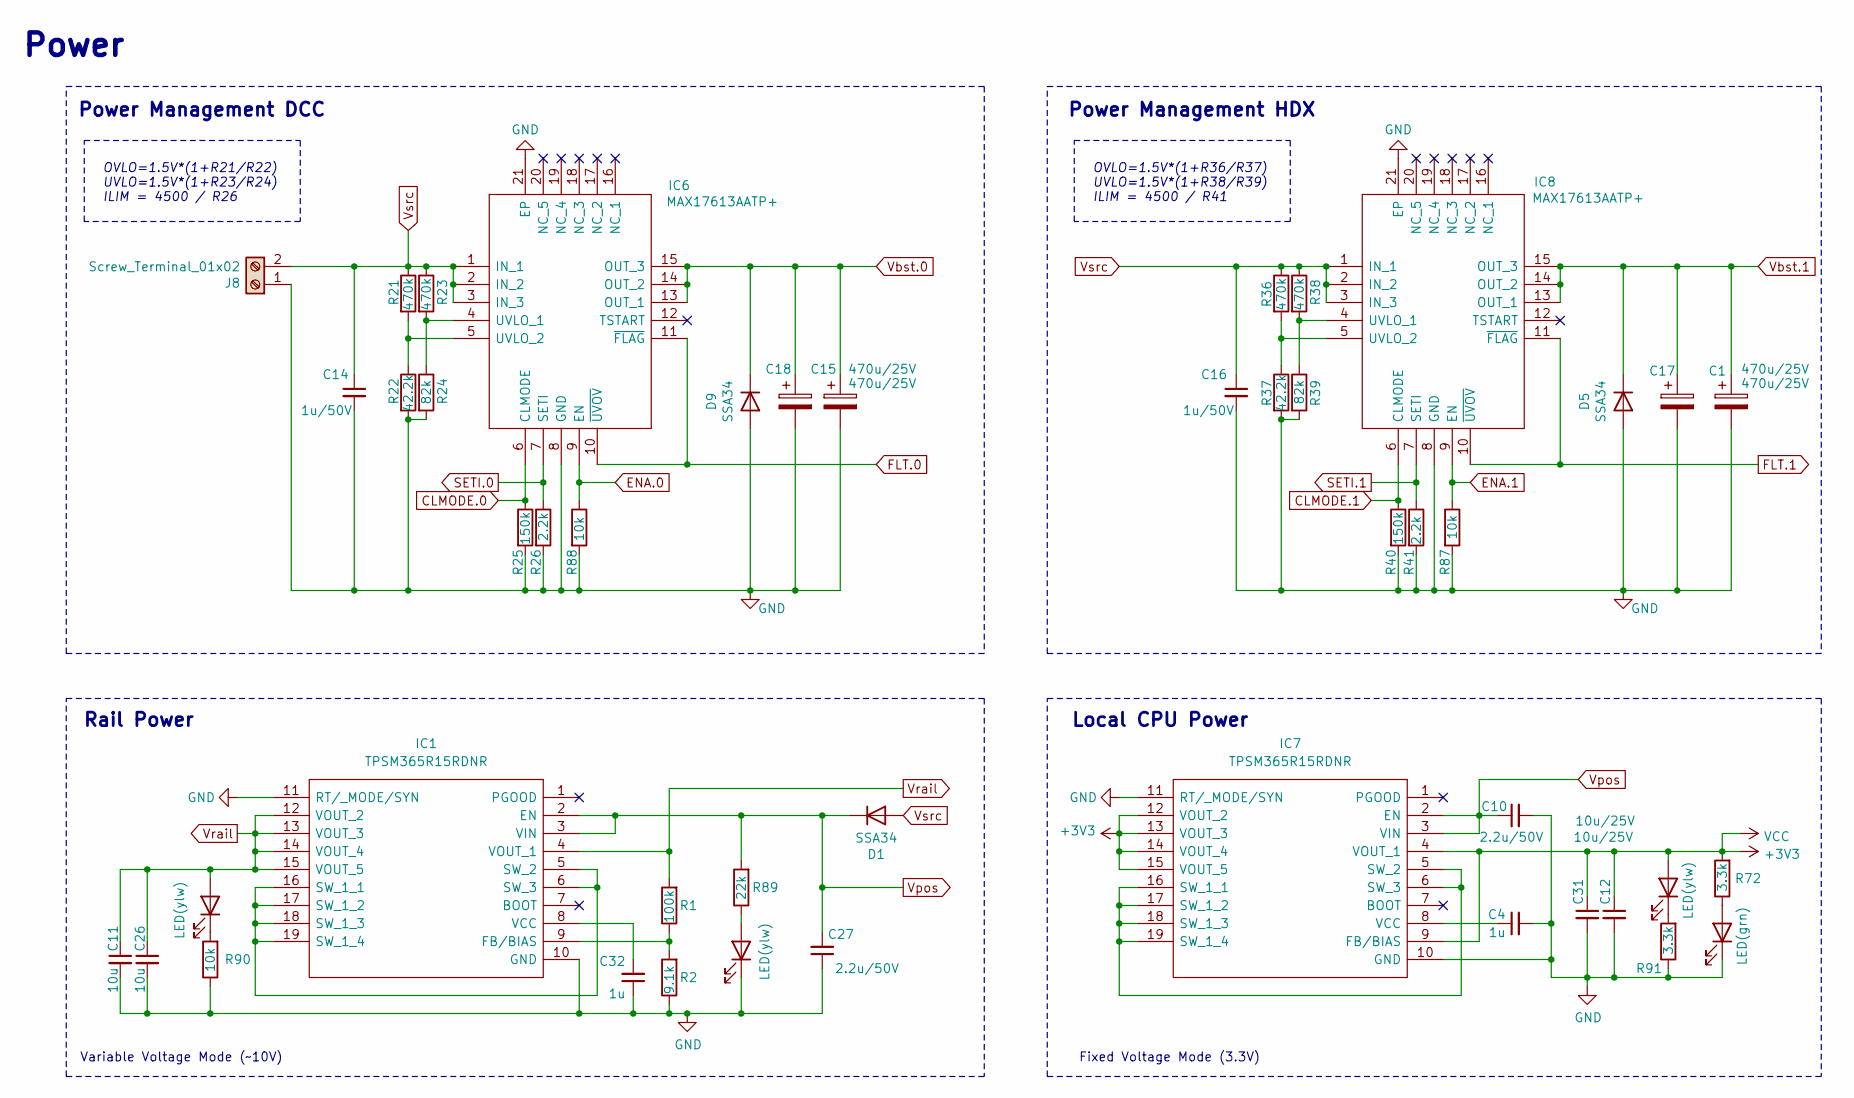
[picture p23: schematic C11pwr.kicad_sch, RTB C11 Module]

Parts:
C1, C15, C17, C18: 470u/25V; CP_Radial_D10.0mm_P5.00mm
C4, C32: 1u; C_0402_1005Metric; LCSC Part # C52923
C10, C27: 2.2u/50V; C_1206_3216Metric; LCSC Part # C50254
C11, C26: 10u; C_1206_3216Metric; LCSC Part # C694197
C12, C31: 10u/25V; C_0603_1608Metric; LCSC Part # C96446
C14, C16: 1u/50V; C_0805_2012Metric; LCSC Part # C28323
D1, D5, D9: SSA34; D_SOD-123F; LCSC Part # C84632
D2: LED(grn); LED_0603_1608Metric
D14, D25, D26: LED(ylw); LED_0603_1608Metric
IC1, IC7: TPSM365R15RDNR; TPSM365R3RDNR; LCSC Part # C22427405
IC6, IC8: MAX17613AATP+; UQFN-20-1EP_4x4mm_P0.5mm_EP2.8x2.8mm_ThermalVias; LCSC Part # C3198161
J8: Screw_Terminal_01x02; TerminalBlock_RND_205-00001_1x02_P5.00mm_Horizontal
R1: 100k; R_0402_1005Metric; LCSC Part # C25741
R2: 9.1k; R_0402_1005Metric; LCSC Part # C25926
R21, R23, R36, R38: 470k; R_0603_1608Metric; LCSC Part # C23178
R22, R37: 42.2k; R_0603_1608Metric; LCSC Part # C23167
R24, R39: 82k; R_0603_1608Metric; LCSC Part # C23254
R25, R40: 150k; R_0603_1608Metric; LCSC Part # C22807
R26, R41: 2.2k; R_0603_1608Metric; LCSC Part # C4190
R72, R91: 3.3k; R_0603_1608Metric; LCSC Part # C22978
R87: 10k; R_0402_1005Metric; LCSC Part # C25744
R88, R90: 10k; R_0603_1608Metric; LCSC Part # C25804
R89: 22k; R_0603_1608Metric; LCSC Part # C31850

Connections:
+3V3: C12.1, C31.1, D26.2 (A), IC7.4 (VOUT_1), IC7.9 (FB/BIAS), IC7.12 (VOUT_2), IC7.13 (VOUT_3), IC7.14 (VOUT_4), IC7.15 (VOUT_5), R72.2; also elsewhere on the board
CLMODE.0: IC6.6 (CLMODE), R25.1; also elsewhere on the board
CLMODE.1: IC8.6 (CLMODE), R40.1; also elsewhere on the board
ENA.0: IC6.9 (EN), R88.1; also elsewhere on the board
ENA.1: IC8.9 (EN), R87.1; also elsewhere on the board
FLT.0: IC6.10 (~UVOV), IC6.11 (~FLAG); also elsewhere on the board
FLT.1: IC8.10 (~UVOV), IC8.11 (~FLAG); also elsewhere on the board
GND: C1.2, C4.2, C10.2, C11.2, C12.2, C14.2, C15.2, C16.2, C17.2, C18.2, C26.2, C27.1, C31.2, C32.1, D2.1 (K), D5.2 (A), D9.2 (A), D14.1 (K), IC1.10 (GND), IC1.11 (RT/_MODE/SYN), IC6.8 (GND), IC6.21 (EP), IC7.10 (GND), IC7.11 (RT/_MODE/SYN), IC8.8 (GND), IC8.21 (EP), J8.1, R2.1, R22.2, R24.2, R25.2, R26.2, R37.2, R39.2, R40.2, R41.2, R87.2, R88.2, R90.1, R91.1; also elsewhere on the board
unnamed: D2.2 (A), R72.1
unnamed: D14.2 (A), R89.1
unnamed: D25.1 (K), R90.2
unnamed: D26.1 (K), R91.2
unnamed: IC1.9 (FB/BIAS), R1.1, R2.2
unnamed: IC1.5 (SW_2), IC1.6 (SW_3), IC1.16 (SW_1_1), IC1.17 (SW_1_2), IC1.18 (SW_1_3), IC1.19 (SW_1_4)
unnamed: C32.2, IC1.8 (VCC)
unnamed: IC6.4 (UVLO_1), R23.2, R24.1
unnamed: IC6.5 (UVLO_2), R21.2, R22.1
unnamed: IC7.5 (SW_2), IC7.6 (SW_3), IC7.16 (SW_1_1), IC7.17 (SW_1_2), IC7.18 (SW_1_3), IC7.19 (SW_1_4)
unnamed: C4.1, IC7.8 (VCC)
unnamed: IC8.4 (UVLO_1), R38.2, R39.1
unnamed: IC8.5 (UVLO_2), R36.2, R37.1
SETI.0: IC6.7 (SETI), R26.1; also elsewhere on the board
SETI.1: IC8.7 (SETI), R41.1; also elsewhere on the board
Vbst.0: C15.1, C18.1, D9.1 (K), IC6.13 (OUT_1), IC6.14 (OUT_2), IC6.15 (OUT_3); also elsewhere on the board
Vbst.1: C1.1, C17.1, D5.1 (K), IC8.13 (OUT_1), IC8.14 (OUT_2), IC8.15 (OUT_3); also elsewhere on the board
Vpos: C10.1, C27.2, D1.1 (K), IC1.2 (EN), IC1.3 (VIN), IC7.2 (EN), IC7.3 (VIN), R89.2
Vrail: C11.1, C26.1, D25.2 (A), IC1.4 (VOUT_1), IC1.12 (VOUT_2), IC1.13 (VOUT_3), IC1.14 (VOUT_4), IC1.15 (VOUT_5), R1.2; also elsewhere on the board
Vsrc: C14.1, C16.1, D1.2 (A), IC6.1 (IN_1), IC6.2 (IN_2), IC6.3 (IN_3), IC8.1 (IN_1), IC8.2 (IN_2), IC8.3 (IN_3), J8.2, R21.1, R23.1, R36.1, R38.1; also elsewhere on the board

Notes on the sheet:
Power
Power Management HDX
Local CPU Power
Rail Power
Power Management DCC
OVLO=1.5V*(1+R36/R37) UVLO=1.5V*(1+R38/R39) ILIM = 4500 / R41
Variable Voltage Mode (~10V)
OVLO=1.5V*(1+R21/R22) UVLO=1.5V*(1+R23/R24) ILIM = 4500 / R26
Fixed Voltage Mode (3.3V)

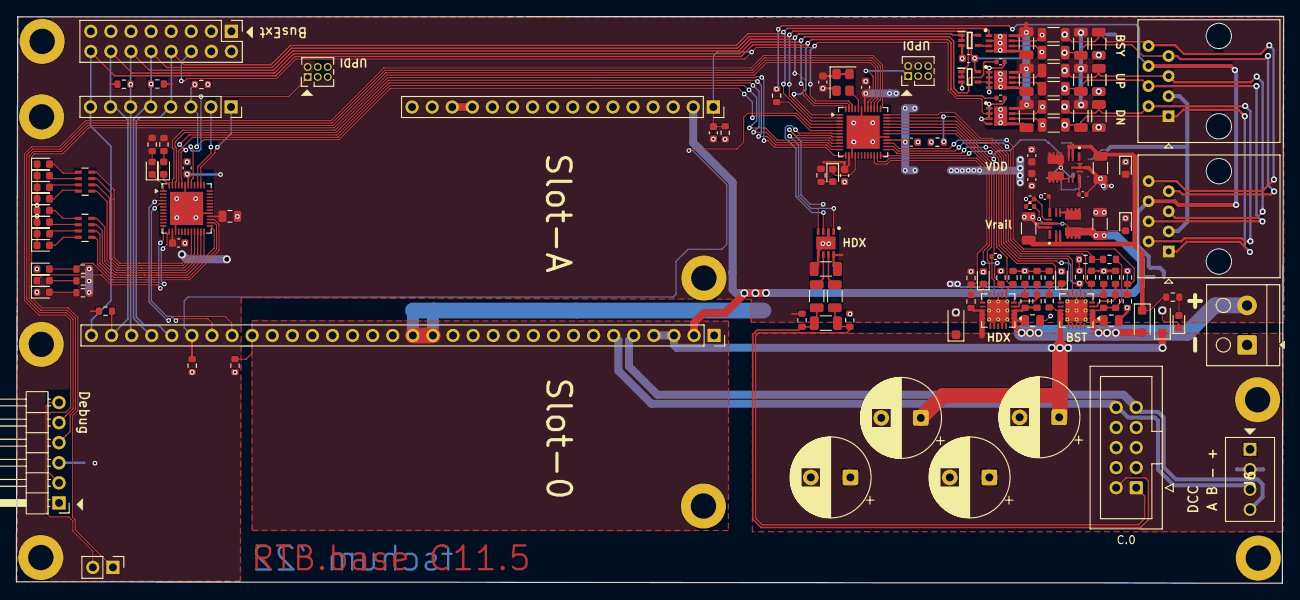
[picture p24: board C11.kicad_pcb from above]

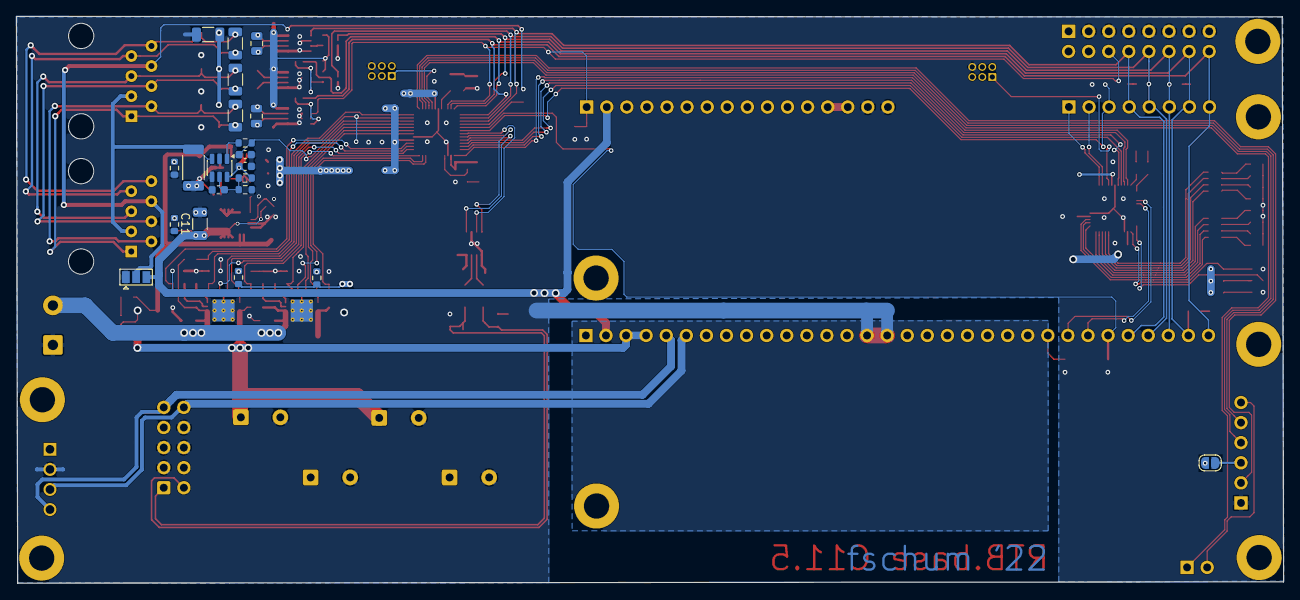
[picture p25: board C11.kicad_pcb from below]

Board: 2 copper layers, 160.3 x 71.7 mm, 163 parts (21 on the bottom side), 117 nets.

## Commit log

2025-10-13 mod: conversion to KiCad 9
    [C11.kicad_pcb, C11.kicad_sch, C11bus.kicad_sch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]
2025-11-04 mod: changed to buck converter
    [C11.kicad_pcb, C11_4_bom.csv, C11bus.kicad_sch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]
2025-11-04 Add Kicad links to README
    Added Kicad section with links to schematic, layout, and Gerber files.
2025-11-18 add: fuses document
2025-11-18 Add UPDI and fuse settings information
    Added section on UPDI and fuse settings with image.
2026-06-15 refined BOM
    [C11.kicad_pcb, C11.kicad_sch, C11bus.kicad_sch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]

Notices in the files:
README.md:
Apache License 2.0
